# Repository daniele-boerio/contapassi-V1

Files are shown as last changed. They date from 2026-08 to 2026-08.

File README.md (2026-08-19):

# Setup Claude Code — contapassi

## Struttura del repo

```
contapassi/
├── .claude/
│   ├── CLAUDE.md                       ← contesto sempre caricato
│   └── skills/
│       ├── kicad-jlcpcb/SKILL.md
│       ├── nrf52840-firmware/SKILL.md
│       └── analisi-andatura/SKILL.md
├── .gitignore
├── README.md
│
├── docs/
│   ├── 01-design.md
│   ├── 02-bom-jlcpcb.md
│   ├── 03-firmware-taratura.md
│   └── datasheet/              ← E73, LSM6DSV16X, MCP73831, cella
│
├── hardware/
│   ├── contapassi.kicad_pro
│   ├── contapassi.kicad_sch
│   ├── contapassi.kicad_pcb
│   ├── lib/
│   │   ├── contapassi.kicad_sym
│   │   ├── contapassi.pretty/  ← footprint
│   │   └── 3dmodels/
│   └── production/
│       └── 2026-XX-XX-v1/      ← gerber + BOM + CPL di ogni ordine
│
├── firmware/
│   ├── CMakeLists.txt
│   ├── prj.conf
│   ├── boards/                 ← definizione board custom
│   └── src/
│
├── analysis/
│   ├── notebooks/
│   ├── src/                    ← parser, ZUPT, metriche
│   └── data/
│       ├── raw/                ← dump binari (NON versionati)
│       └── ground-truth.csv    ← versionato, è prezioso
│
└── ios/
```

### Le scelte che contano

**`lib/` va dentro `hardware/`.** KiCad risolve le librerie di progetto con
`${KIPRJMOD}`, che punta alla cartella del `.kicad_pro`. Fuori da lì i percorsi
si rompono appena sposti il progetto.

**Un solo repo, non tre.** Hardware, firmware e analisi cambiano insieme: se
sposti un pin nello schematico devi toccare anche il firmware. Con repo separati
quella correlazione si perde, e il CLAUDE.md andrebbe duplicato.

**`hardware/production/` con una cartella datata per ordine.** I file di
produzione sono generati, ma sono l'unica traccia di _cosa hai effettivamente
ordinato_. Quando la scheda arriva e qualcosa non torna, vuoi guardare i file
spediti — non rigenerarli da un progetto nel frattempo modificato.

**`firmware/boards/` non è opzionale.** L'nRF Connect SDK ha bisogno di una
definizione di board per il PCB custom: è lì che si dichiara quali pin sono SPI,
dove stanno gli interrupt e la configurazione del quarzo. È la traduzione in
codice della mappatura pin del doc 01.

**`analysis/data/raw/` fuori da git** — sono ~27 MB al giorno di dump, il repo
diventerebbe ingestibile in una settimana. Tienili in una cartella sincronizzata
o su un disco esterno.

**`ground-truth.csv` invece va versionato.** È piccolo e irripetibile: sono le
camminate fatte contando i passi a mano. Se lo perdi, rifai tutta la raccolta.

### .gitignore minimo

```gitignore
# KiCad
*-backups/
*.kicad_prl
*.bak
fp-info-cache
~*.*

# Firmware
build/

# Analisi
analysis/data/raw/
__pycache__/
.ipynb_checkpoints/
```

`.kicad_prl` è escluso ma `.kicad_pro` no: il primo contiene preferenze locali di
visualizzazione, il secondo le impostazioni di progetto da condividere.

## CLAUDE.md vs skill — la differenza

**CLAUDE.md** viene caricato in ogni conversazione. Contiene solo ciò che serve
sempre: cos'è il progetto, le decisioni congelate, i vincoli non negoziabili.
Tenerlo corto è importante — occupa contesto a ogni messaggio.

**Le skill** si caricano solo quando servono, in base alla loro `description`.
Contengono il dettaglio operativo di un dominio specifico. Le tre qui sono
disgiunte: hardware/produzione, firmware, analisi dati.

## Le tre skill

| Skill | Si attiva su |
| --- | --- |
| `kicad-jlcpcb` | KiCad, schematico, PCB, footprint, BOM, CPL, componenti, ordini |
| `nrf52840-firmware` | Codice firmware, driver, BLE, interrupt, consumo, bring-up |
| `analisi-andatura`  | Python, notebook, ZUPT, stance detection, taratura, validazione |

## Verifica che funzionino

In Claude Code, `/skills` elenca le skill disponibili. Se una non compare,
controlla che il frontmatter YAML sia valido e che `name` coincida con il nome
della cartella.

Per testare il triggering, prova richieste generiche e osserva se la skill si
attiva:

- "aggiungi un condensatore di bypass all'IMU" → `kicad-jlcpcb`
- "perché il consumo in idle è più alto del previsto?" → `nrf52840-firmware`
- "il conteggio passi sbaglia sulle camminate lente" → `analisi-andatura`

Se una skill non si attiva quando dovrebbe, il problema è quasi sempre nella
`description`: aggiungi i termini che l'utente userebbe realmente. Le descrizioni
sono volutamente "spinte" (elencano molti sinonimi e casi generici) proprio
perché la tendenza tipica è di non attivarle abbastanza.

## Manutenzione

Le skill contengono numeri che possono cambiare — budget energetico, quote,
codici LCSC. Quando un documento in `docs/` cambia, **controlla se la skill
corrispondente ripete quel numero**. Meglio ancora: dove possibile la skill
rimanda al documento invece di duplicare il valore.

I punti attualmente duplicati e da tenere allineati:

- budget ~161 µA e autonomia ~10 giorni (CLAUDE.md, firmware)
- quote PCB 24 × 41 mm (kicad-jlcpcb)
- codice LCSC del modulo `C356849` (CLAUDE.md, kicad-jlcpcb)
- configurazione IMU ±16 g / 416 Hz (firmware, analisi)

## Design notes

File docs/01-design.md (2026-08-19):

# Contapassi ad alta precisione — Documento di design

**Versione doc:** 1.1
**Stato:** requisiti congelati, **mappatura pin verificata (§5)**, schematico da disegnare
**Target produzione:** KiCad 9.0 → JLCPCB (PCB + PCBA)

---

## 1. Obiettivo

Dispositivo indossabile da caviglia per misurare con precisione:

- **conteggio passi** (24/7)
- **distanza percorsa** (errore target < 1%)
- **parametri di andatura**: cadenza, tempo di appoggio/volo, variabilità del passo

Sincronizzazione con iPhone via BLE, scrittura su HealthKit.
Autonomia target: **1 settimana** (progettato per ~10 giorni reali).
**Indossabile in continuo**, doccia e piscina incluse — mai da togliere.

### Non obiettivi (esplicitamente esclusi)

- Asimmetria destra/sinistra → richiede due unità sincronizzate
- Cinematica del tronco (tilt/obliquità/rotazione pelvica) → richiede posizione lombare
- Classificazione posturale (seduto/in piedi/sdraiato) → impossibile da caviglia
- Display, GPS, cardiofrequenzimetro

---

## 2. Decisione di posizionamento

**Scelta: caviglia**, sopra il malleolo.

| Criterio | Caviglia | Lombare (L3-L5) |
|---|---|---|
| Conteggio passi | ✅ superiore (cammino lento/strascicato) | buono |
| Distanza | ✅ **< 1% via ZUPT**, senza calibrazione | 2-4% via modello, calibrazione personale |
| Eventi temporali (heel strike, toe off) | ✅ precisi al ms | indiretti |
| Cinematica tronco | ❌ | ✅ |
| Asimmetria dx/sx con 1 device | ❌ | ✅ |
| Postura | ❌ | ✅ |
| Qualità RF | ❌ 10 cm da terra, peggiore | ✅ |
| Vincolo ingombro | ✅ permissivo | 4-5 mm max (schienale sedia) |

**Motivazione:** priorità dichiarata = passi + distanza. Lo ZUPT è possibile solo
dove il segmento corporeo si ferma completamente a ogni passo, cioè al piede/caviglia.

---

## 3. Principio ZUPT (Zero Velocity Update)

L'integrazione dell'accelerazione per ottenere posizione accumula errore
quadraticamente: in ~10 s la stima è inutilizzabile.

A ogni passo però il piede resta **fermo a terra per ~0,3-0,5 s**. In quella
finestra la velocità reale è nota e vale zero. Quindi:

1. Rileva la fase di appoggio (stance detection)
2. Azzera velocità e correggi la deriva del giroscopio
3. Integra solo la fase di volo successiva
4. Ripeti

L'errore non si accumula mai oltre una singola falcata.
Analogia: NTP che risincronizza un clock che deriva.

**Conseguenza architetturale:** il giroscopio deve essere attivo durante *tutto*
il cammino, non a campione. Non è duty-ciclabile.

---

## 4. Architettura hardware

```
  pogo (+) ──▶ TVS + prot. inversione ──▶ MCP73831 ──▶ LiPo 301220 (80 mAh, con PCM)
                                              │              │
                                            /STAT            │
                                              │              ▼
                                         ┌────┴───────────  VDH  (VDDH)
                                         │  E73-2G4M08S1C
                                L1 ──── DCH   (nRF52840)
                             (~10 µH)     │                   │
                                  SWD ────┤              2.4 GHz ~~~
                                         │
                          Y1 ─── XL1/XL2 ─┤
                     (32,768 kHz + 2C)    │
                                         │
                        ┌─── SPI condiviso ───┐
                        │                     │
                 LSM6DSV16XTR            W25Q256JVEIQ
               (CS1 + INT1/INT2)           (CS2)
                                        [SOLO v1]
```

Dominio di tensione: **3,0 V** (REGOUT0 configurato via UICR — vedi doc 02 §3).

Topologia di alimentazione verificata sulla *circuit configuration no. 4* del
datasheet Nordic (VDDH + EXTSUPPLY + DCDCEN0 + DCDCEN1):

- LiPo → `VDH` (VDDH)
- **L1 = 10 µH** tra `DCH` (DCCH) e `VDD`: l'induttore sta sull'uscita di REG0,
  non sull'ingresso. Nordic specifica IDC ≥ 80 mA, ±10%, 0603
- `VDD` (pad 19) è **l'uscita di REG0 a 3,0 V** e alimenta IMU e flash.
  Richiede `EXTSUPPLY` abilitato nell'UICR (vedi doc 02 §3)

> ⚠️ **VEXDIF = 0,3 V.** REG0 non può regolare più vicino di 0,3 V al VDDH.
> Con REGOUT0 = 3,0 V il rail è garantito solo finché la cella sta **sopra
> 3,3 V**; sotto, VDD scende seguendo VDDH − 0,3 V. Vedi doc 02 §3.

### 4.1 Decisioni chiave e motivazioni

| # | Decisione | Motivo |
|---|---|---|
| 1 | **Pedometro in hardware nel sensore + FIFO** | MCU sveglio < 1% del tempo. È ciò che rende possibile una cella da poche decine di mAh. Event-driven, mai polling |
| 2 | **Modulo radio certificato, non chip nudo** | Antenna 2.4 GHz già progettata, adattata e certificata. Elimina una classe di problemi non diagnosticabili senza strumenti RF |
| 3 | **Batteria diretta su VDDH** | L'nRF52840 ha regolatore interno, accetta fino a 5,5 V. Elimina l'LDO esterno |
| 4 | **SPI condiviso, non QSPI dedicato** | Il collo di bottiglia del dump è il BLE (~150 kB/s), non la flash. Libera 4 pin, semplifica il layout, e la flash si rimuove pulitamente in v2 |
| 5 | **ZUPT sull'MCU, non su MLC del sensore** | Con budget da 1 settimana l'ottimizzazione non serve più. In C sull'MCU si debugga con un breakpoint, nella FSM del sensore no |
| 6 | **Niente fuel gauge dedicato** | ADC interno + partitore VDDHDIV5 già integrato. Sufficiente su 1 settimana |
| 7 | **v1 logger, v2 prodotto** | Algoritmo tarato sui propri dati, sviluppato offline in Python. Ciclo di iterazione in secondi anziché ore |
| 8 | **DFU over BLE dal giorno 1** | La capsula è annegata in resina: dopo il potting non esiste accesso via cavo |
| 9 | **Doppio tap come unico "pulsante"** | Rilevamento in hardware nell'IMU. Zero componenti, zero aperture, funziona attraverso la resina |
| 10 | **Capsula separata dal cinturino** | Il cinturino è la parte che si consuma e va iterata più volte. Non deve portarsi via l'elettronica |
| 11 | **Dominio a 3,0 V** (REGOUT0 via UICR) | Il default sarebbe 1,8 V. A 3,0 V restano compatibili flash standard, LED di qualsiasi colore e debugger a 3,3 V fissi. Il guadagno energetico a 1,8 V è marginale |
| 12 | **Induttore REG0 esterno (L1)** | Il modulo E73 espone `DCH` → non è integrato. Senza, REG0 resta in LDO e dissipa il 25% su tutto il consumo della scheda |
| 13 | **Quarzo 32,768 kHz esterno (Y1)** | Il modulo espone `XL1`/`XL2` → non è integrato. Senza, l'RC interno allarga le finestre RX BLE e consuma di più proprio dove ottimizziamo |

---

## 5. Mappatura pin — ricostruita sul pinout Ebyte

**Stato:** ✅ **verificata il 2026-08-19.** Fonti:

- *E73-2G4M08S1C User Manual* v1.9 (Ebyte, 2020-03-30), §3 "Size and pin definition"
  → copia locale in `docs/datasheet/`
- *nRF52840 Product Specification*, tabella pin aQFN73 e §56.4 "Circuit
  configuration no. 4" (VDDH + EXTSUPPLY + DCDCEN0 + DCDCEN1 — la nostra topologia)
- footprint generato con `easyeda2kicad --full --lcsc_id=C356849` (geometria dei pad)

### 5.1 Vincolo scoperto: pin "low frequency I/O only"

Nordic marca una parte dei GPIO come **"Standard drive, low frequency I/O only"**,
dove *low frequency* è definita come **segnale fino a 10 kHz**. Su questi pin non
si può appoggiare un bus SPI.

Tra i pad esposti dall'E73 appartengono a questa classe:

`P0.02` `P0.03` `P0.28` `P0.29` `P0.30` `P0.31` (AIN0-1 e AIN4-7),
`P0.09` `P0.10` (NFC), `P1.02` `P1.04` `P1.06` `P1.10` `P1.11` `P1.13`.

**Non** ne fanno parte `P0.04`/`AIN2` e `P0.05`/`AIN3`: hanno funzione analogica
ma nessuna restrizione in frequenza. `P1.00`, `P1.09` e tutta la fascia
`P0.06`-`P0.08`, `P0.12`-`P0.17`, `P0.20`-`P0.26` sono a piena velocità.

> Su 43 pad, i GPIO davvero utilizzabili per SPI ad alta frequenza sono 13.
> È il vincolo che ha determinato l'assegnazione qui sotto.

### 5.2 Pad del modulo

Fila **E** = fila esterna (pad dispari sul lato corto), **I** = fila interna
(pad pari, sotto il corpo del modulo → escape obbligatoriamente su strato interno).

| Pad | Serigrafia | nRF52840 | Classe | Uso nel progetto |
|---|---|---|---|---|
| 1 | `P1.11` | P1.11 | LF | libero |
| 2 | `P1.10` | P1.10 | LF | libero |
| 3 | `P0.03` | P0.03/AIN1 | LF | libero |
| 4 | `AI4` | P0.28/AIN4 | LF | libero |
| 5 | `GND` | — | power | GND |
| 6 | `P1.13` | P1.13 | LF | libero |
| 7 | `AI0` | P0.02/AIN0 | LF | libero |
| 8 | `AI5` | P0.29/AIN5 | LF | libero |
| 9 | `AI7` | P0.31/AIN7 | LF | ✅ **LED** |
| 10 | `AI6` | P0.30/AIN6 | LF | ✅ **CHG_STAT** |
| 11 | `XL1` | P0.00/XL1 | — | ✅ **Y1** |
| 12 | `P0.26` | P0.26 | full, I | ✅ **SPI MISO** |
| 13 | `XL2` | P0.01/XL2 | — | ✅ **Y1** |
| 14 | `P0.06` | P0.06 | full, I | ✅ **SPI MOSI** |
| 15 | `AI3` | P0.05/AIN3 | full, E | ✅ **IMU_INT1** |
| 16 | `P0.08` | P0.08 | full, I | ✅ **SPI SCK** |
| 17 | `P1.09` | P1.09 | full, E | ✅ **IMU_INT2** |
| 18 | `AI2` | P0.04/AIN2 | full, I | riserva (portare a test pad) |
| 19 | `VDD` * | VDD | power | ✅ **rail 3,0 V** (uscita REG0) |
| 20 | `P12` | P0.12 | full, I | ✅ **CS_FLASH** |
| 21 | `GND` | — | power | GND |
| 22 | `P0.07` | P0.07 | full, I | ✅ **CS_IMU** |
| 23 | `VDH` | VDDH | power | ✅ **LiPo diretta** |
| 24 | `GND` | — | power | GND |
| 25 | `DCH` | DCCH | power | ✅ **L1 10 µH → VDD** |
| 26 | `RST` | P0.18/RESET | reset | test pad |
| 27 | `VBS` | VBUS | power | non collegato |
| 28 | `P15` | P0.15 | full | libero |
| 29 | `D-` | USB D- | — | non collegato |
| 30 | `P17` | P0.17 | full | libero |
| 31 | `D+` | USB D+ | — | non collegato |
| 32 | `P0.20` | P0.20 | full | libero |
| 33 | `P0.13` | P0.13 | full | libero |
| 34 | `P0.22` | P0.22 | full | libero |
| 35 | `P0.24` | P0.24 | full | libero |
| 36 | `P1.00` | P1.00 | full | libero |
| 37 | `SWD` | SWDIO | debug | ✅ **pad SWD** |
| 38 | `P1.02` | P1.02 | LF | libero |
| 39 | `SWC` | SWDCLK | debug | ✅ **pad SWD** |
| 40 | `P1.04` | P1.04 | LF | libero |
| 41 | `NF1` | P0.09/NFC1 | LF + NFC | ❌ non usare |
| 42 | `P1.06` | P1.06 | LF | libero |
| 43 | `NF2` | P0.10/NFC2 | LF + NFC | ❌ non usare |

\* Il simbolo EasyEDA chiama questo pad `VCC`; il manuale Ebyte lo chiama `VDD`.
È lo stesso pad 19.

### 5.3 Geometria dei pad

Dal footprint generato (origine al centro del modulo, 13 × 18 mm):

- **Lato corto "freddo"** (pad 11-25), opposto all'antenna: due file sfalsate,
  dispari sulla fila esterna, pari sulla fila interna (sotto il corpo)
- **Lati lunghi**: pad 1-10 su un lato, pad 26-43 sull'altro, anch'essi sfalsati
- **Antenna**: striscia di ~2,2 mm sul lato corto opposto ai pad 11-25 → è lì
  che va il keepout

### 5.4 Assegnazione funzionale — congelata

| Segnale | nRF52840 | Pad | Note |
|---|---|---|---|
| SPI SCK | `P0.08` | 16 | piena velocità |
| SPI MOSI | `P0.06` | 14 | piena velocità |
| SPI MISO | `P0.26` | 12 | piena velocità |
| CS_IMU | `P0.07` | 22 | pull-up 10k |
| CS_FLASH | `P0.12` | 20 | pull-up 10k — **non montato in v2** |
| IMU_INT1 | `P0.05` | 15 | watermark FIFO |
| IMU_INT2 | `P1.09` | 17 | wake / doppio tap |
| CHG_STAT | `P0.30` | 10 | open-drain, pull-up 100k |
| LED | `P0.31` | 9 | resistore in serie |
| riserva | `P0.04` | 18 | unico pin veloce ancora libero sul lato freddo |

### 5.5 Perché questa assegnazione

1. **Tutto il traffico veloce sul lato corto opposto all'antenna.** SPI, interrupt
   e alimentazione escono dallo stesso lato: le tracce commutanti non passano mai
   vicino all'antenna, e IMU e flash si piazzano tutti in quella zona.
2. **Interrupt sulla fila esterna** (pad 15 e 17): sono gli unici due pin veloci
   della fila esterna del lato freddo, e non richiedono escape sotto il modulo.
3. **CHG_STAT e LED sui pin LF** del lato lungo, quelli più vicini al lato freddo:
   sono segnali lenti, sprecare pin veloci su di loro sarebbe stato un errore.
4. **`P0.04` tenuto libero**: è l'ultima risorsa veloce. Portarlo a un test pad
   costa nulla ora e vale molto se in bring-up serve una linea in più.

### 5.6 Pin vietati

| Pin | Motivo |
|---|---|
| `P0.00` / `P0.01` (pad 11/13) | quarzo 32,768 kHz (Y1) |
| `P0.09` / `P0.10` (pad 41/43) | NFC di default; usabili come GPIO solo via UICR `NFCPINS`, e sono comunque LF |
| `P0.18` (pad 26) | reset |
| tutti i pin **LF** | mai per SCK/MOSI/MISO — vedi §5.1 |

### 5.7 Conseguenze sul layout

- I cinque segnali SPI escono da pad della **fila interna**, sotto il corpo del
  modulo: l'escape va fatto con via verso uno strato interno. Ebyte raccomanda
  esplicitamente di **non** far passare routing digitale veloce sullo strato
  opposto sotto il modulo e di mettere rame ben collegato a massa sotto l'area di
  contatto → **L2 piano di massa continuo sotto il modulo**, segnali su L3.
- I pad `SWD`/`SWC` (37/39) stanno sul lato lungo, dalla parte dell'antenna: le
  tracce verso i test pad vanno portate sul lato freddo restando fuori dalla zona
  di keepout.
- `DCH` (25) è il nodo di commutazione di REG0: L1 va tenuto corto e il loop
  `VDH` → L1 → `VDD` compatto, lontano da `XL1`/`XL2` (pad 11/13).

---

## 6. Budget energetico

Assunzioni: cella **301220** (80 mAh dichiarati, 60 prudenti), derating 85%,
DC/DC attivo, sync oraria, advertising 2 s. L'autonomia scala linearmente con la capacità reale:
0,161 mA × 24 h = **3,9 mAh al giorno**.

| Voce | Corrente |
|---|---|
| Idle (accel LP + pedometro, MCU sleep, flash DPD, leakage) | 26 µA |
| Sessioni giroscopio (ZUPT, ~90 min/giorno) | 123 µA |
| Radio (advertising + connessioni) | 10 µA |
| Varie | 2 µA |
| **Totale** | **~161 µA** |
| **Autonomia** | **~18 giorni** sugli 80 mAh dichiarati, **~13 giorni** sui 60 mAh prudenti |

> ⚠️ Valori tipici da datasheet a 25 °C / 3,0 V. **Da verificare sul silicio
> reale** appena la board è funzionante.

**Fase di taratura (v1):** la flash assorbe ~20 mA in scrittura → circa +200 µA
medi durante il logging, cioè ~361 µA totali. Autonomia in logging **~6-8
giorni**: una settimana di camminate si registra senza toccare il caricabatterie.

---

## 7. Meccanica

| Parametro | Valore |
|---|---|
| PCB | **24 × 41 mm**, 4 strati, spessore 0,8 mm |
| Capsula | **~28 × 45 × 5,1 mm** |
| Cella | LiPo **301220** (3,0 × 12 × 20 mm), **80 mAh dichiarati**, PCM integrato |
| Costruzione | Capsula rigida in resina (potting) + guaina silicone platinico separata |

> ⚠️ **Quote cresciute** rispetto al piano iniziale (26 × 14 mm / 30 × 16 × 5 mm):
> il modulo E73 è 18 × 13 mm, contro i 15,5 × 10,5 mm dell'MDBT50Q previsto.
> Alla caviglia, sotto i pantaloni, resta comodo — ma l'outline va fissato ora.

### Disposizione "corta e larga" — decisa il 2026-08-20

Il vincolo dichiarato è: **capsula bassa, ma non lunga**. 61 mm non sono
indossabili, e il modulo da solo ne occupa 18.

Niente si sovrappone in verticale, ma invece di mettere tutto in fila si sfrutta
la **larghezza**: la cella occupa mezza scheda in larghezza, e nell'altra metà
ci stanno carica e alimentazione.

| Zona | Y | Faccia superiore | Faccia inferiore |
|---|---|---|---|
| **cella** | 0-21 mm | a destra solo rame (pogo, pad di test), a sinistra carica e alimentazione | **cella** 12 × 20, a destra |
| **modulo** | 22-41 mm | modulo a sinistra, striscia componenti a destra (IMU, flash, quarzo) | libera |
| **antenna** | 37,4-41 mm | keepout su tutti e 4 gli strati | keepout |

**Spessore: 0,8 (PCB) + 3,3 (cella con tolleranza) + 2 × 0,5 (resina) = 5,1 mm.**
Scheda 24 × 41 mm, capsula ~28 × 45 × 5,1 mm.

Assemblaggio **su una faccia sola**: sul retro c'è solo la cella, incollata. I due
fili passano in fori passanti e si saldano davanti.

### Il modulo è il pavimento: 3,0 mm

Sotto i 4,8 mm non si scende senza cambiare modulo. Le tre voci:

- **modulo E73: 3,00 ± 0,1 mm** — ✅ confermato sul **disegno meccanico** del
  manuale Ebyte (pag. 6), non solo sul modello 3D. Modulo completo:
  18,0 ± 0,1 × 13,0 ± 0,1 × 3,00 ± 0,1 mm, 43 pad
- PCB 0,8 mm — già il minimo sensato a 4 strati
- pareti di resina 0,5 mm per lato

Tutto il resto (IMU 0,83, flash 0,8, carica ~1,1, bulk 1206 ~1,6) sta comodamente
sotto i 3,0 mm e non tocca il totale, perché vive nella zona B dove la faccia
opposta è vuota.

### Cella: 301220, e perché non una più grande

La 401220 del piano iniziale era spessa 4,0 mm e da sola avrebbe portato la
capsula a 5,8 mm. La 301220 è la stessa pianta, 1 mm più sottile.

**La larghezza della cella è vincolata, non libera.** La cella occupa metà della
larghezza della scheda; l'altra metà serve per carica e alimentazione, che
devono stare vicino ai pad del modulo. Una cella da 20 mm di larghezza (es. la
302025 da 140 mAh) lascerebbe 3 mm: non ci sta niente, e L1 finirebbe a 10 mm
dal pad `DCH` invece che a 4.

| | Capacità | Larghezza | Effetto |
|---|---|---|---|
| **301220** ✅ | 80 mAh dichiarati | 12 mm | resta spazio per l'alimentazione |
| 302025 | ~140 mAh dichiarati | 20 mm | scheda +14 mm oppure alimentazione lontana dal modulo |

80 mAh × 0,85 ÷ 0,161 mA = **~18 giorni**, ben oltre il requisito di §1. La
capacità in più della 302025 non serviva e costava lunghezza.

### Dati della cella acquistata

Fonte: pagina del venditore (AliExpress, modello 301220, ~4,7 €/pz in confezione
da 3). Non è un datasheet, ma dichiara i parametri che servono.

| Parametro | Valore | Conseguenza |
|---|---|---|
| Dimensioni | 3 × 12 × 20 mm | ✅ combacia con la zona cella del layout |
| Capacità | 80 mAh dichiarati | autonomia ~18 giorni |
| **PCM** | **integrato** ✅ | requisito soddisfatto |
| Corrente di carica max | **1C** = 80 mA | i nostri 50 mA sono 0,63C ✅ |
| Carica standard | 0,5C CC fino a 4,25 V, poi CV | il MCP73831 fa esattamente questo |
| Scarica max | 1C | irrilevante: noi tiriamo 0,16 mA |
| Fine scarica | **2,75 V** | ⚠️ vedi sotto |
| Fili | liberi, rosso/nero | ✅ vanno diretti nei due fori di J2 |

> ⚠️ **I 80 mAh sono ottimistici.** 3 × 12 × 20 mm fanno 0,72 cm³, cioè
> 411 Wh/l: sopra quello che ci si aspetta da una cella piccola con PCM
> (250-350). **Contare su 55-70 mAh reali** → 12-15 giorni. Misurare la capacità
> vera alla prima carica completa.

> 🔴 **Il PCM stacca a 2,75 V, ma la flash muore prima.** Con VEXDIF = 0,3 V
> (doc 02 §3.2), a cella 2,75 V il rail vale ~2,45 V, sotto il minimo della
> W25Q256JV (2,7 V). La protezione della cella **non** protegge i dati: il
> firmware deve smettere di scrivere in flash sotto i ~3,2 V di cella, molto
> prima che intervenga il PCM.

> **Perché allungare non dà fastidio.** L'asse lungo della capsula corre **lungo
> la gamba**, dove il profilo è quasi rettilineo: 52 mm sopra il malleolo ci
> stanno. È la *larghezza* che deve avvolgere la circonferenza, e resta a 21 mm.

### Vincoli non negoziabili

1. **Antirotazione.** Il sensore misura su tre assi fissi: hanno significato solo
   se l'orientamento rispetto alla gamba è ripetibile. Serve **incastro con
   chiavetta meccanica**, non attrito.
2. **Keepout antenna.** Sotto l'antenna del modulo: nessun rame su nessuno strato,
   nessuna vite, **e mai la sacca LiPo** (è alluminio, spegne l'antenna).
   Il modulo va a un'estremità, con il lato antenna che sporge oltre il bordo
   della cella. Quell'estremità orientata **verso l'alto** sulla gamba.
3. **Vincolo agli urti.** 10-16 g a ogni tallonata. La cella va bloccata con
   schiuma precompressa prima del potting: nessuna massa libera, nessun
   componente alto.
4. **Cinturino sopra il malleolo**, dove la gamba si allarga: il conico impedisce
   lo scivolamento verso il basso.
5. **Pogo pin sulla faccia esterna**, non contro la pelle (sudore + contatti =
   accoppiamento pessimo). Recessati in una scanalatura per non strisciarli
   sui pantaloni.

### Tenuta stagna

Requisito: **doccia e piscina senza toglierlo**. Il potting previsto per gli urti
risolve anche l'acqua — stessa scelta, doppio beneficio. La pressione non è il
vincolo (una piscina è ~0,2 bar): il vincolo è la **tenuta nel tempo**.

| Punto | Requisito |
|---|---|
| Pogo pin | Unico foro nella capsula. Già sulla faccia esterna |
| Cella LiPo | **Sigillata completamente**, non solo protetta. È il componente che soffre di più l'umidità nel lungo periodo |
| Guaina | Silicone platinico: regge cloro e acqua salata |

**🔴 Regola d'uso da mettere nell'app:** mai in carica se bagnato.
Contatti umidi + corrente = corrosione garantita. In acqua senza tensione
applicata non succede nulla; il danno avviene al momento della ricarica.
Sciacquare con acqua dolce dopo il mare.

> **Perché non si toglie:** rimetterlo con un orientamento diverso rompe la
> ripetibilità dei dati — lo stesso motivo per cui esiste la chiavetta
> antirotazione. Meglio un dispositivo che riconosce il nuoto (doc 03 §5)
> che uno da togliere e rimettere.

### Scartato

**Batteria distribuita nel cinturino** per assottigliare la capsula: richiede un
flex che si flette a ogni passo per mesi. Modo affidabile di introdurre un guasto
intermittente impossibile da diagnosticare.

---

## 8. Comunicazione iPhone

Nessun MFi richiesto: BLE con GATT custom + app propria.

### Due canali separati

| | Sync sommario | Dump grezzo |
|---|---|---|
| Contenuto | Passi/ora, distanza, batteria | Log completo a 416 Hz |
| Frequenza | Ogni ora, pochi secondi | Solo sotto carica, solo v1 |
| Volume | Centinaia di byte | Decine di MB |

Con **2M PHY + Data Length Extension** su iPhone: ~120-170 kB/s reali.

### Vincoli iOS da rispettare in fase di progetto

1. **MTU:** iOS accetta fino a 185 byte di payload nelle notifiche. Usa
   **notifiche, non indicazioni** (le indicazioni aspettano l'ack → throughput
   dimezzato).
2. **Connection interval:** Apple impone minimo 15 ms e multiplo di 15. Parametri
   non conformi vengono rifiutati e resti sui default.
   Sync sommario → intervallo lungo + slave latency alta. Dump → intervallo minimo.
3. **Background:** serve il background mode `bluetooth-central` con **State
   Preservation and Restoration**. In background iOS scansiona **solo per UUID di
   servizio espliciti**, mai wildcard → l'UUID custom va cablato nell'app.
4. **Advertising:** 2 s di default (pochi µA). Finestra veloce solo su evento
   (movimento rilevato, dispositivo sul caricatore).

### HealthKit

Scrittura come `HKQuantityTypeIdentifier.stepCount`.

> ⚠️ Anche l'iPhone scrive i propri passi. Salute **non somma** le sorgenti
> sovrapposte: sceglie in base alla priorità delle sorgenti impostata dall'utente.
> Va gestito: o si accetta la priorità utente, o si tengono i propri dati in un
> contenitore separato usando HealthKit solo per un totale consolidato.

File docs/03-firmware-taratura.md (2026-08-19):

# Firmware e protocollo di taratura

**Principio guida:** prima si esplorano i dati in un notebook, poi si porta in
produzione. Scrivere l'algoritmo prima di avere i propri dati significa tararlo
sull'andatura di qualcun altro.

---

## 1. Le due versioni

| | **v1 — Logger** | **v2 — Prodotto** |
|---|---|---|
| Hardware | Con flash W25Q256JVEIQ | Flash non montata (DNP) |
| Firmware | Solo acquisizione e scrittura | Algoritmo in C a bordo |
| Algoritmi | Nessuno | ZUPT, pedometro, metriche |
| Elaborazione | Offline in Python sul PC | Real-time sul dispositivo |
| Autonomia | 2-4 giorni | ~10 giorni |
| Scopo | Raccogliere dataset personale | Uso quotidiano |

**Vantaggio del logger:** ciclo di iterazione in secondi anziché ore, con grafici.
Sul firmware ogni prova richiede compilazione, flash, camminata, scarico.

---

## 2. Firmware v1 (logger)

### Pin (dal doc 01 §5.4 — unica fonte, non riscriverli a mano)

| Segnale | nRF52840 |
|---|---|
| SPI SCK / MOSI / MISO | `P0.08` / `P0.06` / `P0.26` |
| CS_IMU / CS_FLASH | `P0.07` / `P0.12` |
| IMU_INT1 / IMU_INT2 | `P0.05` / `P1.09` |
| CHG_STAT / LED | `P0.30` / `P0.31` |
| riserva | `P0.04` |

> `P0.30` e `P0.31` sono pin **"low frequency I/O only"** (≤ 10 kHz): vanno bene
> per un LED e per uno stato di carica, mai per un bus.

### Vincoli che arrivano dallo schematico

- **LED in erogazione, non in assorbimento.** `P0.31` → 1 kΩ → LED → GND: a
  3,0 V con un LED rosso scorre ~1 mA, sopra i 0,5 mA garantiti dal drive
  standard. Configurare il pin in **HIGH drive** (`H0H1`), altrimenti il LED
  resta smorto e la tensione di uscita non è quella attesa
- **Tensione di batteria: nessun partitore.** Si legge con il SAADC sull'ingresso
  interno **VDDHDIV5** (VDDH diviso 5). Non c'è hardware da pilotare, ma il
  fattore 5 va rimesso nel conto
- **`CHG_STAT` è open-drain** con pull-up da 100 kΩ: basso = in carica, alto =
  carica finita **oppure caricatore assente**. I due casi si distinguono solo
  incrociando con la tensione di VDDH
- **Flash: `WP#` e `HOLD#` sono tirati alti con 10 kΩ**, non collegati fissi a
  VDD. In v1 vanno lasciati in pace; servono se un giorno si volesse il quad SPI
- **`P0.04` è portato a un pad di test** ed è l'unico GPIO veloce ancora libero

### Funzioni minime

- Configurazione IMU: **±16 g, 416 Hz, 6 assi**
  *(gli impatti tibiali in corsa superano i 16 g; 416 Hz serve per timbrare bene
  heel strike e toe off)*
- FIFO del sensore + interrupt watermark su INT1
- Buffer in RAM, **scrittura su flash a blocchi grossi**
- Pedometro hardware attivo in parallelo (per il gating)
- DFU over BLE
- Dump della flash via BLE quando sul caricatore

### ⚠️ Regola non negoziabile: scrittura a blocchi

La W25Q assorbe ~20 mA in scrittura. Chiamarla a ogni campione distrugge il budget
energetico. L'nRF52840 ha 256 kB di RAM: accumulare lì e svuotare a blocchi.

### ⚠️ Il logging deve essere gattato

Data rate: 6 assi × 16 bit × 416 Hz ≈ **5,0 kB/s → 18 MB/h**.

Su 32 MB → solo ~1,8 h di registrazione continua.

**Soluzione:** attivare il logging solo sui bout di cammino rilevati dal pedometro
hardware. Si scende a ~27 MB/giorno di dati effettivamente utili, e non si portano
a casa 15 ore di rumore da stare seduto.

### Formato dei dati

Includere sempre nel record:

- Timestamp (o contatore campioni + timestamp di blocco)
- 3 assi accelerometro
- 3 assi giroscopio
- Marker di inizio/fine sessione
- Temperatura (utile per valutare la deriva del giroscopio)

---

## 3. Protocollo di raccolta dati

### Sessione base — pista di atletica (400 m)

Registrare **5 andature**, ciascuna su distanza nota, contando i passi a mano:

| # | Andatura | Distanza | Note |
|---|---|---|---|
| 1 | Camminata molto lenta | 200 m | Il caso peggiore per i contapassi |
| 2 | Camminata normale | 400 m | — |
| 3 | Camminata veloce | 400 m | — |
| 4 | Corsa leggera | 400 m | — |
| 5 | Corsa sostenuta | 200 m | Verifica saturazione a ±16 g |

Per ognuna annotare: **distanza reale, passi contati a mano, tempo**.

### Sessione complementare — tapis roulant

Non sostituisce la pista, la integra. Il tapis dà **velocità impostabile,
ripetibile e controllata**; la pista dà la **verità assoluta sulla distanza**
(il display del tapis è calibrato sui giri del nastro, non è un riferimento
affidabile al livello di precisione cercato).

> **Perché i dati sono validi:** un nastro a velocità costante è un sistema di
> riferimento inerziale. Nel riferimento del nastro il piede è *davvero* fermo
> durante l'appoggio → **lo ZUPT resta valido** e le misure inerziali sono
> identiche a quelle di una camminata all'aperto alla stessa andatura.
> Nessuna gestione speciale nel firmware.

Sweep sistematico, 5 minuti per velocità:

| Velocità | Nota |
|---|---|
| 3 km/h | Camminata lenta |
| 4 km/h | Camminata normale |
| 5 km/h | Camminata veloce |
| 6 km/h | Transizione cammino/corsa |
| 8 km/h | Corsa leggera |
| 10 km/h | Corsa — verifica saturazione ±16 g |

Ripetere a pendenza 0% e 5% per valutare l'effetto sulla lunghezza di falcata.

**Limiti da tenere presenti:**

- **Transitori:** durante accelerazione/decelerazione del nastro il riferimento
  non è più inerziale → errore per qualche secondo. Scartare quelle finestre
- **Slittamento del nastro** sotto carico: piccolo errore, ma è del tapis
- **Pendenza:** misuri distanza percorsa, non dislivello (resti alla stessa quota).
  Corretto così — contare i piani richiederebbe il barometro, tolto passando
  alla caviglia

### Sessioni aggiuntive (casi difficili)

- Scale in salita e in discesa (conteggio gradini noto)
- Cammino in pendenza
- Cammino con carrello della spesa / passeggino
- Passi strascicati, cammino in casa a passi corti
- Alzarsi e fare 3-4 passi (i primi passi sono il caso peggiore)
- Falsi positivi: stare seduto muovendo la gamba, guidare, andare in bici
- Trasporto passivo: auto, treno, ascensore

### Regola di validazione

**Ogni registrazione deve avere una verità di riferimento annotata.** Un file senza
ground truth non serve a nulla e va scartato.

Tenere un log parallelo (foglio o note) con:
`data / ora inizio / tipo / distanza reale / passi contati / condizioni`

---

## 4. Sviluppo offline in Python

### Pipeline

1. **Parsing** del dump binario → DataFrame
2. **Verifica qualità**: campioni persi, saturazioni, gap temporali
3. **Stance detection** — rilevare le fasi di appoggio
4. **ZUPT** — azzeramento velocità + correzione deriva
5. **Integrazione** delle fasi di volo → lunghezza falcata
6. **Pedometro** — validare il conteggio contro i passi contati a mano
7. **Metriche di andatura** — cadenza, tempo appoggio/volo, variabilità

### Stance detection — approccio

Combinare più condizioni contemporaneamente su una finestra scorrevole:

- Modulo dell'accelerazione vicino a 1 g
- Varianza dell'accelerazione sotto soglia
- Modulo della velocità angolare sotto soglia

Nessuna delle tre da sola è affidabile. Le soglie vanno **tarate sui propri dati**,
ed è esattamente il motivo per cui esiste la fase v1.

### Metriche di andatura ottenibili

- **Cadenza** (passi/min)
- **Variabilità del tempo di passo** (CV) — la più interessante clinicamente
- **Tempo di appoggio / tempo di volo**
- **Durata del doppio supporto**
- **Regolarità** via autocorrelazione: primo picco = regolarità del passo,
  secondo picco = regolarità della falcata

> ❌ Non ottenibili da un solo dispositivo alla caviglia: asimmetria destra/sinistra,
> cinematica del tronco, postura.

### Criterio di uscita dalla fase v1

- [ ] Errore sul conteggio passi < 1% su tutte le andature testate
- [ ] Errore sulla distanza < 1% su percorsi noti
- [ ] Zero falsi positivi in auto/treno/seduto
- [ ] Algoritmo stabile su almeno 3 sessioni indipendenti senza ritaratura

---

## 5. Firmware v2 (prodotto)

### Struttura a eventi

```
MCU in sleep profondo
  │
  ├── INT1 (watermark FIFO) ──▶ svuota FIFO ──▶ elabora ──▶ sleep
  │
  ├── INT2 (movimento) ──────▶ attiva giroscopio, entra in modo cammino
  │
  ├── INT2 (doppio tap) ─────▶ azione utente (es. LED stato batteria)
  │
  ├── Timer 1 h ─────────────▶ advertising rapido, sync BLE, sleep
  │
  └── CHG_STAT ──────────────▶ modo carica: advertising rapido, dump disponibile
```

### Macchina a stati principale

| Stato | Accelerometro | Giroscopio | Consumo |
|---|---|---|---|
| **Idle** | LP + pedometro HW | spento | ~26 µA |
| **Cammino** | full rate | **attivo** (ZUPT) | ~alto |
| **Non deambulatoria** | LP | **spento** | basso |
| **Sync** | LP | spento | picchi TX |
| **Carica** | LP | spento | irrilevante |

Transizione Idle → Cammino: su rilevamento movimento sostenuto.
Transizione Cammino → Idle: dopo N secondi senza passi.
Transizione Cammino → Non deambulatoria: movimento presente ma **nessuna fase di
appoggio valida per N secondi consecutivi**.

**Il giroscopio è il costo dominante.** L'unica leva è entrare in stato Cammino
il più tardi possibile e uscirne il prima possibile — senza però perdere passi.

### 🔴 Stato "attività non deambulatoria"

**Il problema.** Lo ZUPT poggia su un'unica assunzione: che a ogni passo il piede
sia fermo. Nel nuoto, in bici e al remoergometro il piede **non si ferma mai**.
Con soglie permissive l'algoritmo integrerebbe accelerazioni senza mai correggere
la deriva → **distanze completamente inventate**. Non un errore piccolo: rumore.

Il conteggio passi invece è poco a rischio: il pedometro cerca l'impatto del
tallone, che in acqua non esiste.

**La firma inerziale del nuoto è ben distinguibile:**

| Grandezza | Cammino | Nuoto |
|---|---|---|
| Picchi di accelerazione | 10-16 g (tallonata) | 1-2 g |
| Fasi di quiete | Presenti a ogni passo | Assenti |
| Profilo | Impulsivo | Continuo, sinusoidale |
| Orientamento gravità | Stabile | Capovolto nel dorso |

**Comportamento in questo stato:**

- ZUPT sospeso
- Conteggio passi sospeso
- Giroscopio spento → **consumi meno che in stato Cammino**
- Periodo marcato nei dati come "attività non deambulatoria"

Costo implementativo: un ramo in più nella logica di transizione. Protegge anche
da bici e remoergometro, che hanno lo stesso identico problema.

> **Da aggiungere alle sessioni di raccolta (§3):** nuoto, bici, remoergometro.
> Servono per tarare le soglie di questa transizione.

### Dati mantenuti a bordo

- Passi per ora (buffer circolare, almeno 7 giorni)
- Distanza per ora
- Metriche di andatura aggregate per sessione
- Tensione batteria

Il buffer da 7 giorni serve a non perdere dati se l'iPhone non si connette.

### Servizio BLE

GATT custom. Caratteristiche minime:

| Caratteristica | Tipo | Contenuto |
|---|---|---|
| Sommario corrente | read/notify | Passi oggi, distanza, batteria |
| Storico | notify | Buffer orario, trasferito a blocchi |
| Stato dispositivo | read | Firmware, uptime, stato carica |
| Controllo | write | Reset contatori, sincronizza orologio |
| Dump grezzo | notify | Solo v1, solo sotto carica |

> ⚠️ **Sincronizzazione orologio a ogni connessione.** Se il modulo non ha il
> quarzo a 32,768 kHz, l'RC interno deriva sensibilmente. L'app deve riallineare
> l'orologio del dispositivo a ogni sync.

---

## 6. Ordine di implementazione consigliato

0. [ ] **Scrivere REGOUT0 = 3,0 V nell'UICR** (offset 0x304, valore `4`) e
       **verificare EXTSUPPLY = 1** (offset 0x300). Va fatto al primissimo flash:
       il default dell'nRF52840 su VDDH è 1,8 V, e a quella tensione la flash
       W25Q256JVEIQ (2,7-3,6 V) non funziona. Senza EXTSUPPLY dal pad `VDD` non
       si può prelevare corrente → IMU e flash restano morti. Vedi doc 02 §3.1
1. [ ] Bring-up: alimentazione, MCU vivo, LED lampeggia
2. [ ] SWD funzionante, **poi** DFU over BLE (prima del potting!)
3. [ ] Comunicazione SPI con IMU — leggere il registro WHO_AM_I
3b. [ ] Verificare che il quarzo Y1 a 32,768 kHz oscilli e sia selezionato come
        sorgente LFCLK (non l'RC interno)
4. [ ] Comunicazione SPI con flash — leggere il JEDEC ID
5. [ ] Misura del consumo reale in sleep → confronto col budget
6. [ ] FIFO + interrupt watermark
7. [ ] Scrittura su flash a blocchi
8. [ ] Dump via BLE
9. [ ] **→ Fase di raccolta dati (§3)**
10. [ ] **→ Sviluppo offline (§4)**
11. [ ] Porting dell'algoritmo congelato in C
12. [ ] App iOS + HealthKit
13. [ ] v2: rimozione flash, nuovo layout, potting

> Il punto 5 è un gate: se il consumo reale è molto sopra il budget, va capito
> **prima** di investire nell'algoritmo.

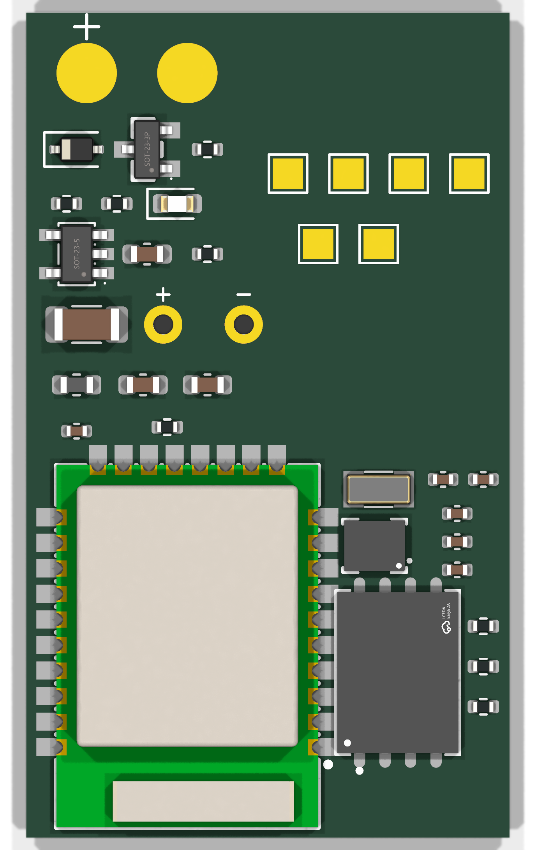
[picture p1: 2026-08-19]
hardware/production/anteprima-piazzamento.png

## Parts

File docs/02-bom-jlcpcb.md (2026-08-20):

# BOM e checklist JLCPCB

**Stato:** componenti verificati sul catalogo JLCPCB. ✅ = confermato in stock.
**Buona notizia trasversale:** tutte le righe hanno **Min: 1**. Nessun minimo
d'ordine forzato — il rischio di costo temuto non si è materializzato.

---

## 1. Tooling

| Cosa | Nota |
|---|---|
| KiCad | **9.0** — restare qui, non aggiornare a metà progetto |
| Plugin | **kicad-jlcpcb-tools** (Bouni) — repo custom, vedi §6 |
| Conversione parti | **easyeda2kicad** — genera simbolo/footprint/3D da codice LCSC |

---

## 2. BOM confermata

| Rif | Componente | LCSC | Package | Stock | Prezzo |
|---|---|---|---|---|---|
| U1 | **E73-2G4M08S1C** (Ebyte, nRF52840) | `C356849` | SMD 18×13 mm | 2437 ✅ | $8,14 |
| U2 | **LSM6DSV16XTR** (ST, IMU 6 assi) | `C5267406` | LGA-14 (2,5×3 mm) | ✅ | ~$2,88 |
| U3 | **W25Q256JVEIQ** (Winbond, 32 MB) | `C97522` | WSON-8-EP (6×8) | 16763 ✅ | €3,76 |
| U4 | **MCP73831T-2ATI/OT** (Microchip) | `C14879` | SOT-23-5 | 1957 ✅ | €0,96 |
| L1 | **MLZ1608M100WT000** (Murata, 10 µH, Isat 90 mA) | `C76798` | 0603 | 61743 ✅ | ~$0,02 |
| Y1 | **Q13FC13500004** (Epson, 32,768 kHz, CL 12,5 pF) | `C32346` | SMD3215-2P | 557062 ✅ **Basic** | ~$0,10 |
| C1, C2 | **18 pF ±5% C0G** (carico di Y1) | `C1549` | 0402 | 1306168 ✅ **Basic** | ~$0,002 |
| C_bulk | **47 µF 10 V** (serbatoio VDDH) | `C96123` | 1206 | 1054417 ✅ **Basic** | ~$0,03 |
| Q1 | **AO3401A** (P-MOSFET, blocco inversione) | `C15127` | SOT-23 | 545691 ✅ **Basic** | ~$0,03 |
| D1 | **PESD5V0S1BA** (TVS bidirezionale 5 V) | `C2827694` | SOD-323 | 1011482 ✅ | ~$0,01 |
| D2 | **LED rosso** | `C2286` | 0603 | 6043727 ✅ **Basic** | ~$0,004 |
| C4, C5, C10 | 4,7 µF 16 V X5R | `C19666` | 0603 | ✅ **Basic** | — |
| C6-C9 | 100 nF 16 V X7R | `C1525` | 0402 | ✅ **Basic** | — |
| R1-R4 | 10 kΩ (pull-up CS_IMU, CS_FLASH, WP#, HOLD#) | `C25744` | 0402 | ✅ **Basic** | — |
| R5, R8 | 100 kΩ (pull-up CHG_STAT, gate di Q1) | `C25741` | 0402 | ✅ **Basic** | — |
| R6 | 20 kΩ (ISET = 50 mA) | `C25765` | 0402 | ✅ **Basic** | — |
| R7 | 1 kΩ (serie LED) | `C11702` | 0402 | ✅ **Basic** | — |
| J1 | **piazzole di contatto** per il cavo magnetico — nessun componente | — | `PogoPads_2P_P5.0mm` | — | — |
| J2 | **piazzole di saldatura** per i fili della cella | — | `CellPads_2P_P4.0mm` | — | — |
| TP1-TP6 | pad di test (SWDIO, SWCLK, GND, +3V0, RESET, P0.04) | — | 1,5 × 1,5 mm | — | — |

**Righe Extended: 6** (U1, U2, U3, U4, L1, D1). Tutto il resto è Basic.

### 🔴 Piazzole invece di pogo pin — cambio rispetto al doc 01 §7

Il doc 01 prevede **pogo pin montati sul dispositivo**. I footprint disegnati
fanno l'opposto: sul dispositivo ci sono **piazzole piatte dorate**, e le molle
stanno sul cavo di ricarica.

**Perché:** un pogo pin è un pistone che si muove. Per montarlo servono un foro
nella capsula e una tenuta attorno a una parte mobile — cioè l'unico punto in cui
la resina non può sigillare niente, sul dispositivo che deve stare in piscina.
Con le piazzole la capsula non ha **nessuna apertura**: la resina si ferma a filo
del rame, e il rame è già dorato se si ordina la finitura **ENIG**.

Costo del cambio: il cavo di ricarica dev'essere del tipo "magnetico con puntali",
non un semplice cavo con contatti piatti.

- [ ] **Decisione da confermare.** Se preferisci i pogo pin sul dispositivo,
      il footprint va rifatto (30 minuti) e il doc 01 §7 resta com'è
- [ ] Il **passo di 5,0 mm** delle piazzole è un valore di partenza: va misurato
      sul cavo magnetico effettivamente acquistato, poi cambiato in
      `hardware/tools/gen_footprints.py` (una riga)
- [ ] Ordinare il PCB con finitura **ENIG**, non HASL: le piazzole di contatto
      sono strisciate mille volte e l'oro non si ossida

### Insieme da non montare in v2

La v2 toglie la flash e quello che serve solo a lei: **U3, R2, R3, R4, C9**.
Stesso layout, cinque righe marcate DNP. Nient'altro cambia.

### Stato dello schematico

Prima stesura generata da `hardware/tools/gen_schematic.py` e verificata:

- **ERC pulito, 0 violazioni** (`kicad-cli sch erc --severity-all`)
- 37 componenti, 26 reti, netlist controllata rete per rete
- I pin non usati del modulo hanno un **no-connect esplicito**, non sono
  semplicemente lasciati vuoti

> ⚠️ È uno schematico **"a netlist"**: i collegamenti sono etichette sui pin, non
> fili tirati a mano. È corretto ma non è leggibile come un disegno fatto bene.
> Va riordinato in Eeschema — e da quel momento **non rilanciare il generatore**,
> che riscrive il file da zero.

I tipi elettrici dei pin (`power_in`, `tri_state`, …) sono assegnati da
`hardware/tools/fix_pin_types.py`: easyeda2kicad li marca tutti `unspecified`, e
con quelli l'ERC non serve a niente. **Va rilanciato dopo ogni rigenerazione di
un simbolo con easyeda2kicad.**

### Stato del layout

Contorno, piazzamento, keepout e piani generati da `hardware/tools/gen_pcb.py`
e verificati con `kicad-cli pcb drc`:

- **0 errori.** Restano 7 avvisi `silk_over_copper` (contorni componente in
  serigrafia che toccano i pad): cosmetici, JLC taglia la serigrafia sui pad
- Keepout antenna su **tutti e 4 gli strati**, tutta la larghezza, da Y 37,4
- Impilaggio: `F.Cu` componenti, `In1.Cu` massa piena (è lo schermo sotto il
  modulo), `In2.Cu` +3V0 pieno, `B.Cu` libero per i segnali
- Sigle dei componenti su `F.Fab`, non in serigrafia: a 24 × 41 mm le scritte
  si sovrapporrebbero ai componenti
- **80 collegamenti da instradare**

### 🔴 L'instradamento automatico è stato tolto

`hardware/tools/route.py` contiene un instradatore scritto per questo progetto.
**Non funziona e non va usato** (`SEGNALI = False`, `VIE = False`).

Il motivo è concreto: l'IMU ha i pad a **passo 0,5 mm**, larghi 0,27 mm. Uscire
da lì richiede di posizionare le piste con precisione inferiore al passo della
griglia dell'instradatore. Con la griglia larga non passava niente; stringendo i
controlli i moncherini di uscita finivano sopra i pad vicini, e il DRC tirava
fuori **18 cortocircuiti veri** su 168 violazioni.

Meglio nessuna pista che piste sbagliate: le piazzole restano vergini e le piste
si tirano in **pcbnew con l'instradatore interattivo**, che il fan-out lo fa
bene e mostra il rats-nest mentre lavori.

Il codice resta nel repository perché la geometria (contorno, keepout, piani)
la genera lo stesso file, non perché l'instradamento vada ripreso.

### Note sui componenti

**U1 — E73-2G4M08S1C.** Sostituisce l'MDBT50Q-1MV2 (non disponibile).
Stesso chip nRF52840, modulo certificato con antenna integrata.

- ✅ **VDDH esposto** (pad `VDH` nel simbolo) → la scelta "LiPo diretta su VDDH"
  resta valida, nessun LDO da reintrodurre
- 🔴 **`DCH` esposto** → l'induttore di REG0 **non è integrato**, va aggiunto (L1)
- 🔴 **`XL1`/`XL2` esposti** → il quarzo 32,768 kHz **non è integrato** (Y1)
- ⚠️ **18 × 13 mm** → il PCB deve crescere (vedi doc 01 §7)
- ⚠️ **X-ray Inspection: Required** → costo aggiuntivo sull'ordine, **e il
  montaggio manuale del solo modulo non è più un'opzione**: ha pad sotto il
  corpo, non solo castellati

> Sigle lette dal simbolo EasyEDA: **confermare tutto sul datasheet Ebyte**
> (link "Download" nella pagina JLCPCB del componente).

**U2 — LSM6DSV16XTR** → `C5267406`, verificato nel catalogo PCBA di JLCPCB
(Extended, LGA-14 2,5×3 mm, MSL 1). "TR" = Tape & Reel, è solo il confezionamento.

> Esiste anche la riga `C42388605` ("LSM6DSV16X", New Arrivals, X-ray richiesta).
> È lo stesso chip: **usare `C5267406`**, e ricontrollare la scorta il giorno
> dell'ordine — la pagina JLC non espone lo stock senza login.

**U3 — W25Q256JVEIQ.** Variante 2,7-3,6 V, compatibile con il dominio a 3,0 V
scelto in §3. Solo v1.

> ⚠️ Se un giorno passassi al dominio a 1,8 V, questa parte **non funziona**.
> La variante corretta sarebbe `C2940048` (W25Q256JWEIQ, 1,7-1,95 V).

**U4 — MCP73831T-2ATI/OT.** Il "2" indica i 4,20 V corretti per LiPo.

- [ ] Aprire il PDF e verificare nella tabella di ordinazione che l'uscita STAT
      di questa variante sia leggibile da GPIO
- [ ] Alternativa se non lo è: `C424093` (`-2ACI/OT`, 2874 pz)
- [x] **Corrente di carica: verificata.** La 301220 scelta dichiara **carica
      max 1C = 80 mA**. I 50 mA di `R6 = 20 kΩ` sono **0,63C**: sotto il massimo
      e sopra i ~50 mA oltre i quali l'MCP73831 lavora con buona precisione.
      Ricarica completa in ~2 ore. Nessun cambio di componente

**L1 — induttore REG0.** Senza, REG0 resta in modalità LDO: scendere da 4,0 V a
3,0 V dissiperebbe il **25% su tutto il consumo della scheda**. Un componente
0603 vale il 25% di autonomia.

✅ **Valore confermato**: *nRF52840 PS*, §56.4 "Circuit configuration no. 4",
tabella 157 (designator L4): **10 µH, chip inductor, IDC min = 80 mA, ±10%,
0603**. Va **tra `DCH` (DCCH) e `VDD`**, cioè sull'uscita di REG0.

🔴 **Trappola: qui il componente Basic non si può usare.** L'unico 10 µH 0603
Basic in catalogo è `C1035` (Sunlord SDFL1608S100KTF) ed è un induttore *di
segnale*: **corrente nominale 3 mA**, DCR 1,85 Ω. Su un convertitore che deve
passare decine di mA satura e basta. Il campo "10 µH 0603" da solo non dice nulla:
va letta la corrente.

| LCSC | Modello | Tolleranza | Isat | I nom. | DCR | Lib |
|---|---|---|---|---|---|---|
| `C1035` | SDFL1608S100KTF | ±10% | — | **3 mA** ❌ | 1,85 Ω | Basic |
| **`C76798`** | **MLZ1608M100WT000** (Murata) | ±20% | **90 mA** ✅ | 250 mA | 1,05 Ω | Extended |
| `C87216` | LBMF1608T100K | ±10% | *non dichiarato* | 80 mA | 0,36 Ω | Extended |
| `C92970` | BRL1608T100M | ±20% | 170 mA | 170 mA | 2 Ω | Extended |

**Scelto `C76798`**: è l'unico che dichiara esplicitamente una **Isat (90 mA)
sopra gli 80 mA richiesti** da Nordic, con 61k pezzi a magazzino. La tolleranza
±20% non è un problema su un induttore di buck — Nordic stessa usa ±20% su L2
nella stessa tabella. `C87216` avrebbe la tolleranza giusta e un DCR migliore,
ma non pubblica la corrente di saturazione: è quella che conta.

**Y1 — quarzo 32,768 kHz.** Non strettamente obbligatorio, ma consigliato: senza,
l'RC interno richiede ricalibrazioni periodiche e **allarga le finestre di
ricezione BLE**, cioè consuma di più proprio dove stiamo ottimizzando. Costa
~2 µA e dà un orologio che non deriva tra una sync e l'altra.

✅ **Specifica confermata**. Il reference design Nordic (tabella 157, X2 + C16/C17)
usa un cristallo **CL 9 pF con due condensatori da 12 pF**; la tabella di specifica
LFXO (§17.4.3) ammette **CL fino a 12,5 pF**, C0 ≤ 2 pF, ESR ≤ 100 kΩ.

**Scelto `C32346`** (Epson Q13FC13500004, 32,768 kHz, ±20 ppm, **CL 12,5 pF**):
è l'unico 3215 **Basic** in catalogo, con 557k pezzi. Nessun costo di caricamento.

Condensatori di carico: dal reference design Nordic (9 pF con 12 pF) si ricava
una capacità parassita di **~3 pF** per ramo, quindi

`C = 2 × (CL − C_parassita) = 2 × (12,5 − 3) = 19 pF` → **18 pF (`C1549`, Basic)**

- [ ] Il valore parassita 3 pF è dedotto dal reference Nordic, non misurato:
      dipende dal layout. Con 18 pF l'errore residuo vale pochi ppm, e il BLE
      ne tollera ±250 → non è un rischio, ma va ricontrollato se un giorno
      servisse precisione d'orologio migliore
- Alternativa "copia esatta del reference": `C99010` (Epson CL 9 pF, Extended,
  45k pezzi) + 2 × `C1547` (12 pF). Costa una riga Extended in più e fa
  partire l'oscillatore un filo prima. Non vale la spesa

### Componenti NON assemblati da JLC (montaggio manuale)

- **Cella LiPo 301220**, 3,0 × 12 × 20 mm, 80 mAh dichiarati, **PCM integrato**,
  fili liberi. Confezione da 3 a ~10,4 € + spedizione (AliExpress, consegna
  ~2 mesi). La prima montata di solito si sacrifica: 3 pezzi sono il numero giusto
- Nessun pogo pin: sul dispositivo ci sono solo piazzole (vedi sopra)

---

## 3. 🔴 Decisione: dominio a 3,0 V

L'nRF52840 alimentato da VDDH ha REGOUT0 che **di default esce a 1,8 V**, e
questo definisce la tensione di tutta la scheda.

**Scelta: 3,0 V**, impostata scrivendo REGOUT0 nell'UICR al primo flash.

| | 3,0 V (scelto) | 1,8 V (default) |
|---|---|---|
| Flash | `C97522` standard | servirebbe `C2940048` |
| IMU | ✅ (1,71-3,6 V) | ✅ |
| LED | ✅ qualsiasi colore | ⚠️ solo rosso, a fatica |
| Programmatore | anche 3,3 V fissi | **VTref obbligatorio** |
| Consumo | leggermente superiore | leggermente inferiore |

Il guadagno energetico a 1,8 V è marginale rispetto al budget; la compatibilità
semplifica flash, LED e debugger.

**Conseguenza:** il vincolo sul programmatore si rilassa — un debugger economico
a 3,3 V fissi funziona. Il VTref resta preferibile ma non è bloccante.

### 3.1 Due registri UICR, non uno

| Registro | Offset | Valore | Nota |
|---|---|---|---|
| `REGOUT0` | 0x304 | `4` = 3,0 V | il default (`7`) è 1,8 V → **va scritto** |
| `EXTSUPPLY` | 0x300 | `1` = Enabled | consente di alimentare IMU e flash dal pad `VDD` |

`EXTSUPPLY` risulta già abilitato su UICR vergine (cancellata = tutti 1), ma va
**verificato dopo ogni `nrfjprog --eraseall`**: con `EXTSUPPLY = 0` dal pad `VDD`
non si può prelevare corrente, e IMU e flash restano senza alimentazione.

### 3.2 🔴 VEXDIF: il rail a 3,0 V non è garantito per tutta la scarica

*nRF52840 PS*, §16.10.1: **VEXDIF = 0,3 V minimo** — REG0 non può produrre una
tensione più vicina di 0,3 V al VDDH.

| VDDH (cella) | VDD (rail) | Stato |
|---|---|---|
| 4,2 → 3,3 V | 3,0 V | regolato |
| < 3,3 V | ≈ VDDH − 0,3 V | **il rail scende con la cella** |
| 3,0 V | ≈ 2,7 V | limite inferiore della flash W25Q256J**V** |

Non è bloccante — sotto i 3,3 V il degrado è graduale e tutto continua a
funzionare (IMU da 1,71 V, radio da 2,5 V su VDDH) — ma va saputo:

- La flash arriva **esattamente** al suo minimo (2,7 V) quando la cella è a 3,0 V.
  In v1, che scrive in flash, conviene fermare il logging sotto ~3,2 V di cella
- L'app deve mostrare "batteria scarica" intorno a 3,3 V, non a 3,0 V
- Altra voce da misurare in bring-up: `IEX,OFF` limita a **1 mA** la corrente
  prelevabile dal pad `VDD` in System OFF → flash in deep power-down obbligatoria

---

## 4. Basic vs Extended

JLCPCB divide i componenti in due categorie. I **Basic** sono già caricati sulle
macchine. Gli **Extended** richiedono caricamento manuale con **costo fisso per
tipo di componente**, indipendente dalla quantità.

Su un lotto da 5 pezzi questo domina il costo totale.

- Modulo, IMU e flash sono inevitabilmente Extended — sono loro il progetto
- [ ] **Tutti i passivi devono essere Basic**
- [ ] **Consolidare i valori**: se servono 47k, 51k e 56k in punti non critici,
      usarne uno solo per tutti e tre

---

## 5. Parametri di produzione

| Parametro | Scelta | Motivo |
|---|---|---|
| Dimensioni | **24 × 41 mm** | Disposizione corta e larga — vedi doc 01 §7 |
| Strati | 4 | — |
| Spessore | **0,8 mm** | Standard, stesso prezzo di 1,6. Guadagna ~1 mm nella capsula |
| Passivi | 0402 | Basic Parts + spazio |
| Assemblaggio | provare su una faccia sola | Il doppio lato costa di più e allunga i tempi |
| Separazione | **V-cut** dove la geometria lo consente | Le mouse bites lasciano sbavature, e la capsula deve incastrarsi con precisione |
| Ispezione | **X-ray obbligatoria** (richiesta dal modulo) | Costo aggiuntivo da mettere a preventivo |

---

## 6. Installazione plugin Bouni

Non è nel repository ufficiale KiCad. Va aggiunto a mano:

1. Plugin and Content Manager → **Gestisci...**
2. **➕** → incolla l'URL:
   `https://raw.githubusercontent.com/Bouni/bouni-kicad-repository/main/repository.json`
3. Nome: `Bouni` → salva
4. Seleziona il nuovo repository dalla tendina in alto
5. Installa **KiCad JLCPCB tools** → **Applica i cambiamenti**

> Se il repository non compare nella tendina, chiudi e riapri il Plugin Manager.

**Nota d'uso:** il plugin assegna i codici LCSC ai *footprint già piazzati sul
PCB*. Per la semplice verifica di disponibilità il sito jlcpcb.com è più rapido.

**Fabrication Toolkit** (bennymeg, nel repo ufficiale) è un'alternativa valida per
generare gerber/BOM/CPL, ma non cerca il catalogo da dentro KiCad.

---

## 7. Trappole note

### 🔴 Rotazioni nel file CPL

Errore numero uno dei primi ordini PCBA. JLCPCB usa convenzioni di orientamento
che spesso **non coincidono** con quelle delle librerie KiCad → componenti saldati
ruotati di 90°. Il plugin ha un **Rotation manager** con le correzioni note.

- [ ] **Controllare sempre l'anteprima grafica** che JLC mostra prima di confermare
- [ ] Verificare componente per componente dove sta il pin 1

### 🔴 Footprint del modulo radio

Usa **easyeda2kicad** con il codice `C356849` invece di disegnarlo a mano: genera
simbolo, footprint e modello 3D.

- [ ] **Verificare comunque il risultato contro il datasheet Ebyte**, in
      particolare il keepout d'antenna. È l'unica zona della scheda dove un
      errore non si recupera con un filo volante

### 🟡 Clearance dal bordo e pannellizzazione

JLC ha una distanza minima dei componenti dal bordo scheda. Il modulo che
"sporge oltre il bordo della batteria" è un requisito **meccanico dentro la
capsula**, non un componente a filo del bordo PCB.

- [ ] Verificare la regola di clearance prima di fissare l'outline
- [ ] Decidere V-cut vs mouse bites **prima** del layout

---

## 8. Ordine dei lavori

1. [x] Verificare i componenti sul catalogo JLCPCB
2. [x] Annotare il codice LCSC dell'LSM6DSV16XTR → `C5267406`
3. [x] Scaricare il datasheet Ebyte E73-2G4M08S1C → `docs/datasheet/`
4. [x] **Rifare la mappatura pin** (doc 01 §5) sul pinout Ebyte
5. [x] L1, Y1 e condensatori di carico scelti sul catalogo JLCPCB (§2)
6. [x] **Cella scelta e verificata: 301220**, 80 mAh, PCM integrato, carica
       max 1C (doc 01 §7)
7. [x] Generare simbolo e footprint con easyeda2kicad → `hardware/lib/`
8. [x] Schematico — prima stesura generata, ERC pulito; **da riordinare a mano**
9. [ ] Layout — [x] contorno, piazzamento, keepout e piani di massa generati;
       resta l'instradamento
10. [ ] Export BOM + CPL con il plugin
11. [ ] Controllo anteprima JLC pin per pin

---

## 9. Checklist pre-ordine

- [ ] DRC pulito
- [ ] ERC pulito
- [ ] Keepout antenna verificato su tutti e 4 gli strati (nessun rame, nessuna via)
- [ ] Induttore REG0 da 10 µH tra `DCH` e `VDD` (non tra `DCH` e `VDH`)
- [ ] Quarzo 32,768 kHz su `XL1`/`XL2` con i condensatori di carico
- [ ] Bulk 47 µF (`C96123`, 1206 10 V) vicino al VDDH del modulo
      *(il 47 µF 0805 da 6,3 V `C16780` perde molta più capacità per DC bias a 4,2 V)*
      *(la cella ha 1-2 Ω di resistenza interna; i picchi TX BLE la fanno affondare
      → brownout casuali durante la sync)*
- [ ] Resistore ISET calcolato per la corrente scelta
- [ ] TVS e protezione inversione sui pogo pin
      *(contatti esposti = ingresso preferito delle ESD; i pogo magnetici verranno
      attaccati al buio, storti, mille volte)*
- [ ] Pull-up su CS_IMU e CS_FLASH
- [ ] Pull-up su CHG_STAT
- [ ] Nessun segnale SPI su un pin "low frequency I/O only" (doc 01 §5.1)
- [ ] **4 pad SWD ben distanziati + punto di GND ampio**, accessibili prima del potting
- [ ] Modelli 3D verificati contro l'ingombro della capsula
- [ ] Anteprima JLC controllata pin 1 per pin 1

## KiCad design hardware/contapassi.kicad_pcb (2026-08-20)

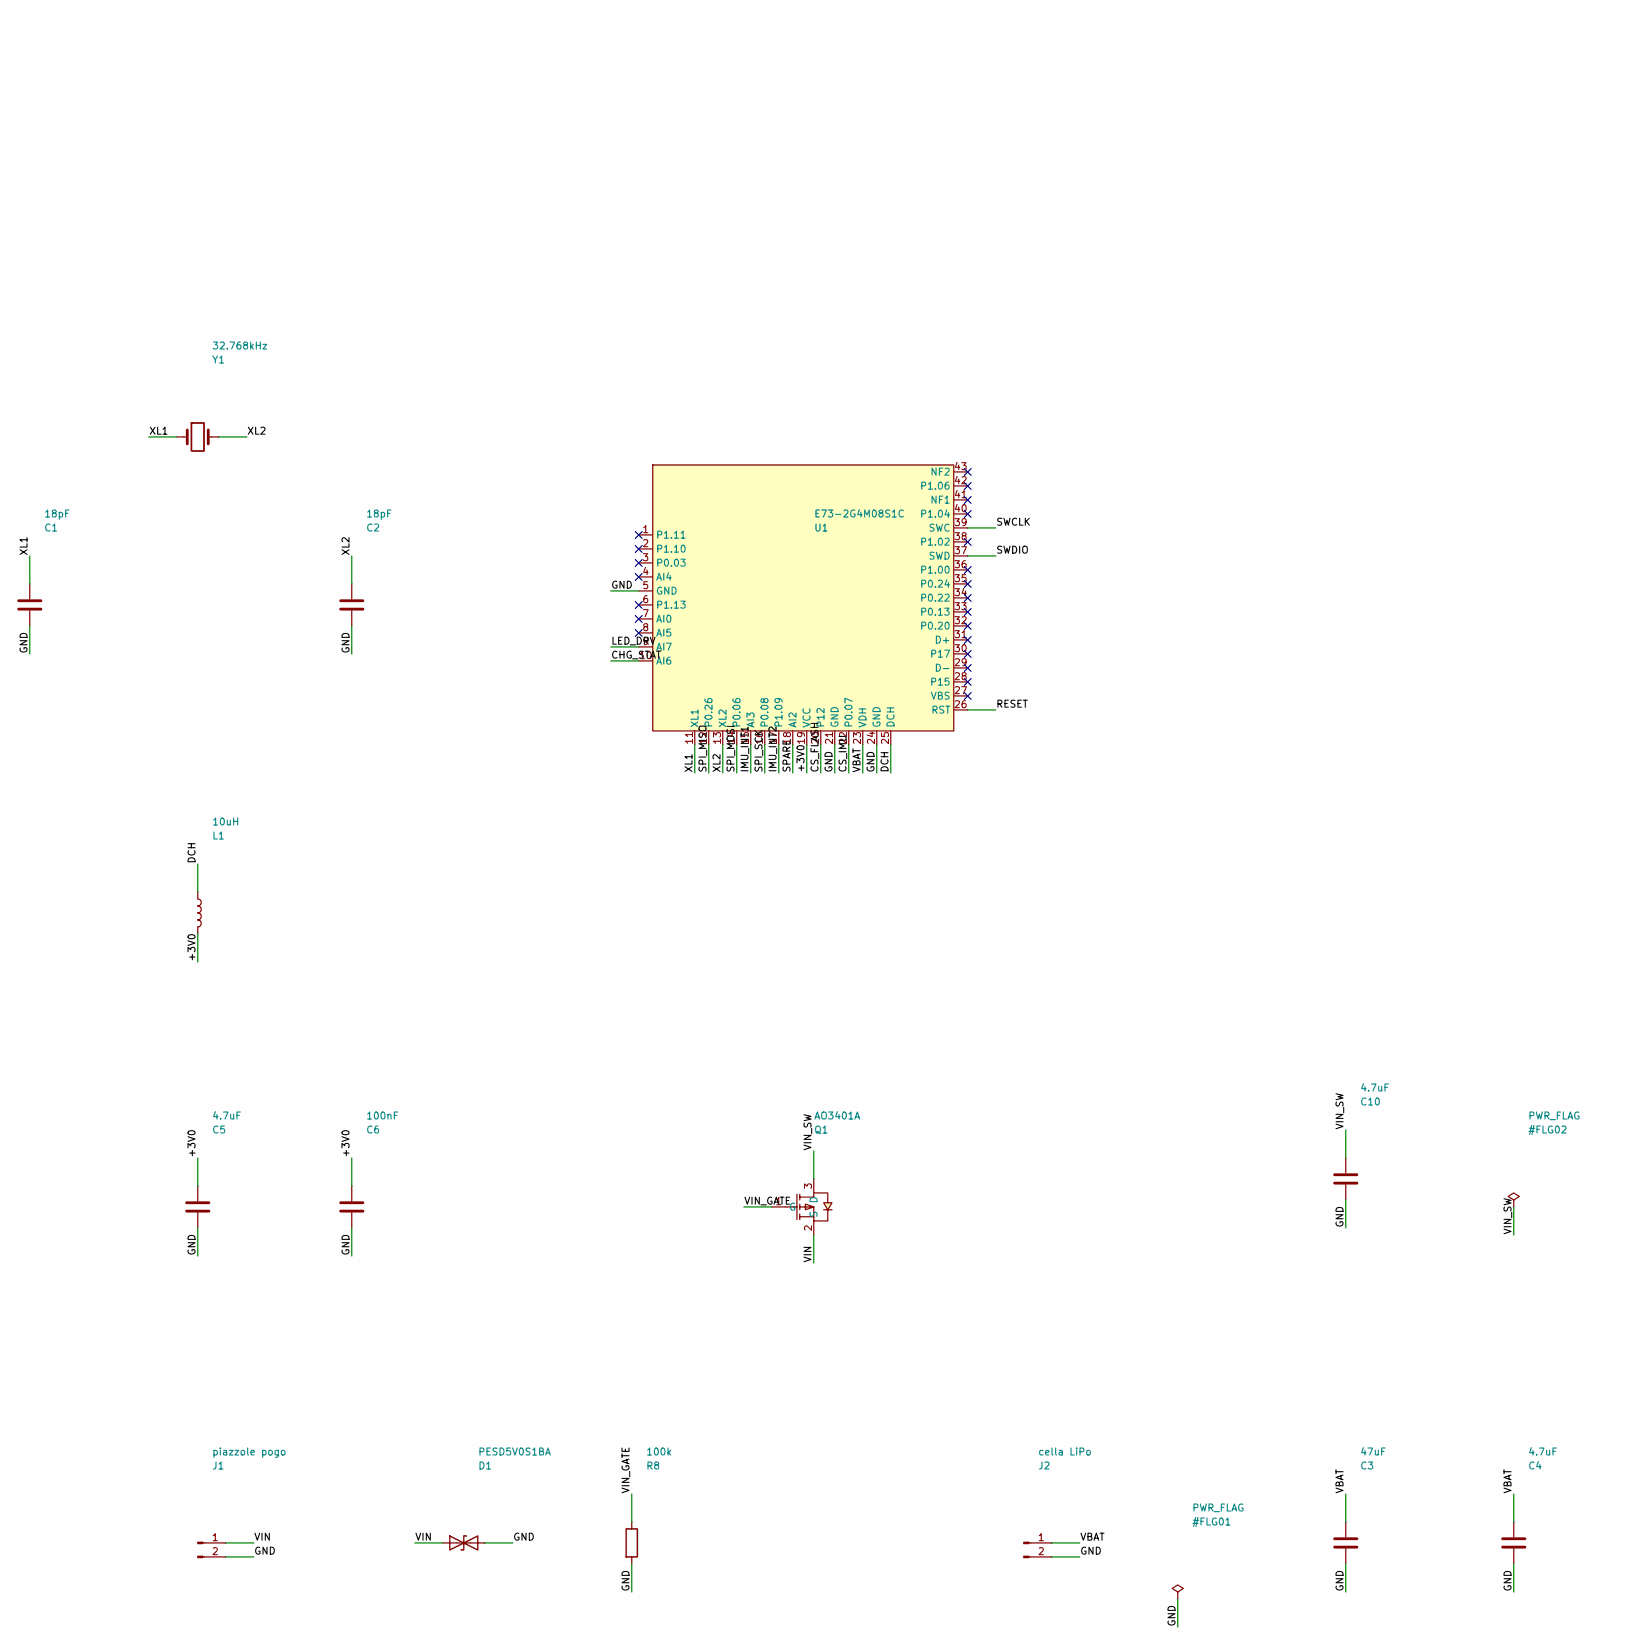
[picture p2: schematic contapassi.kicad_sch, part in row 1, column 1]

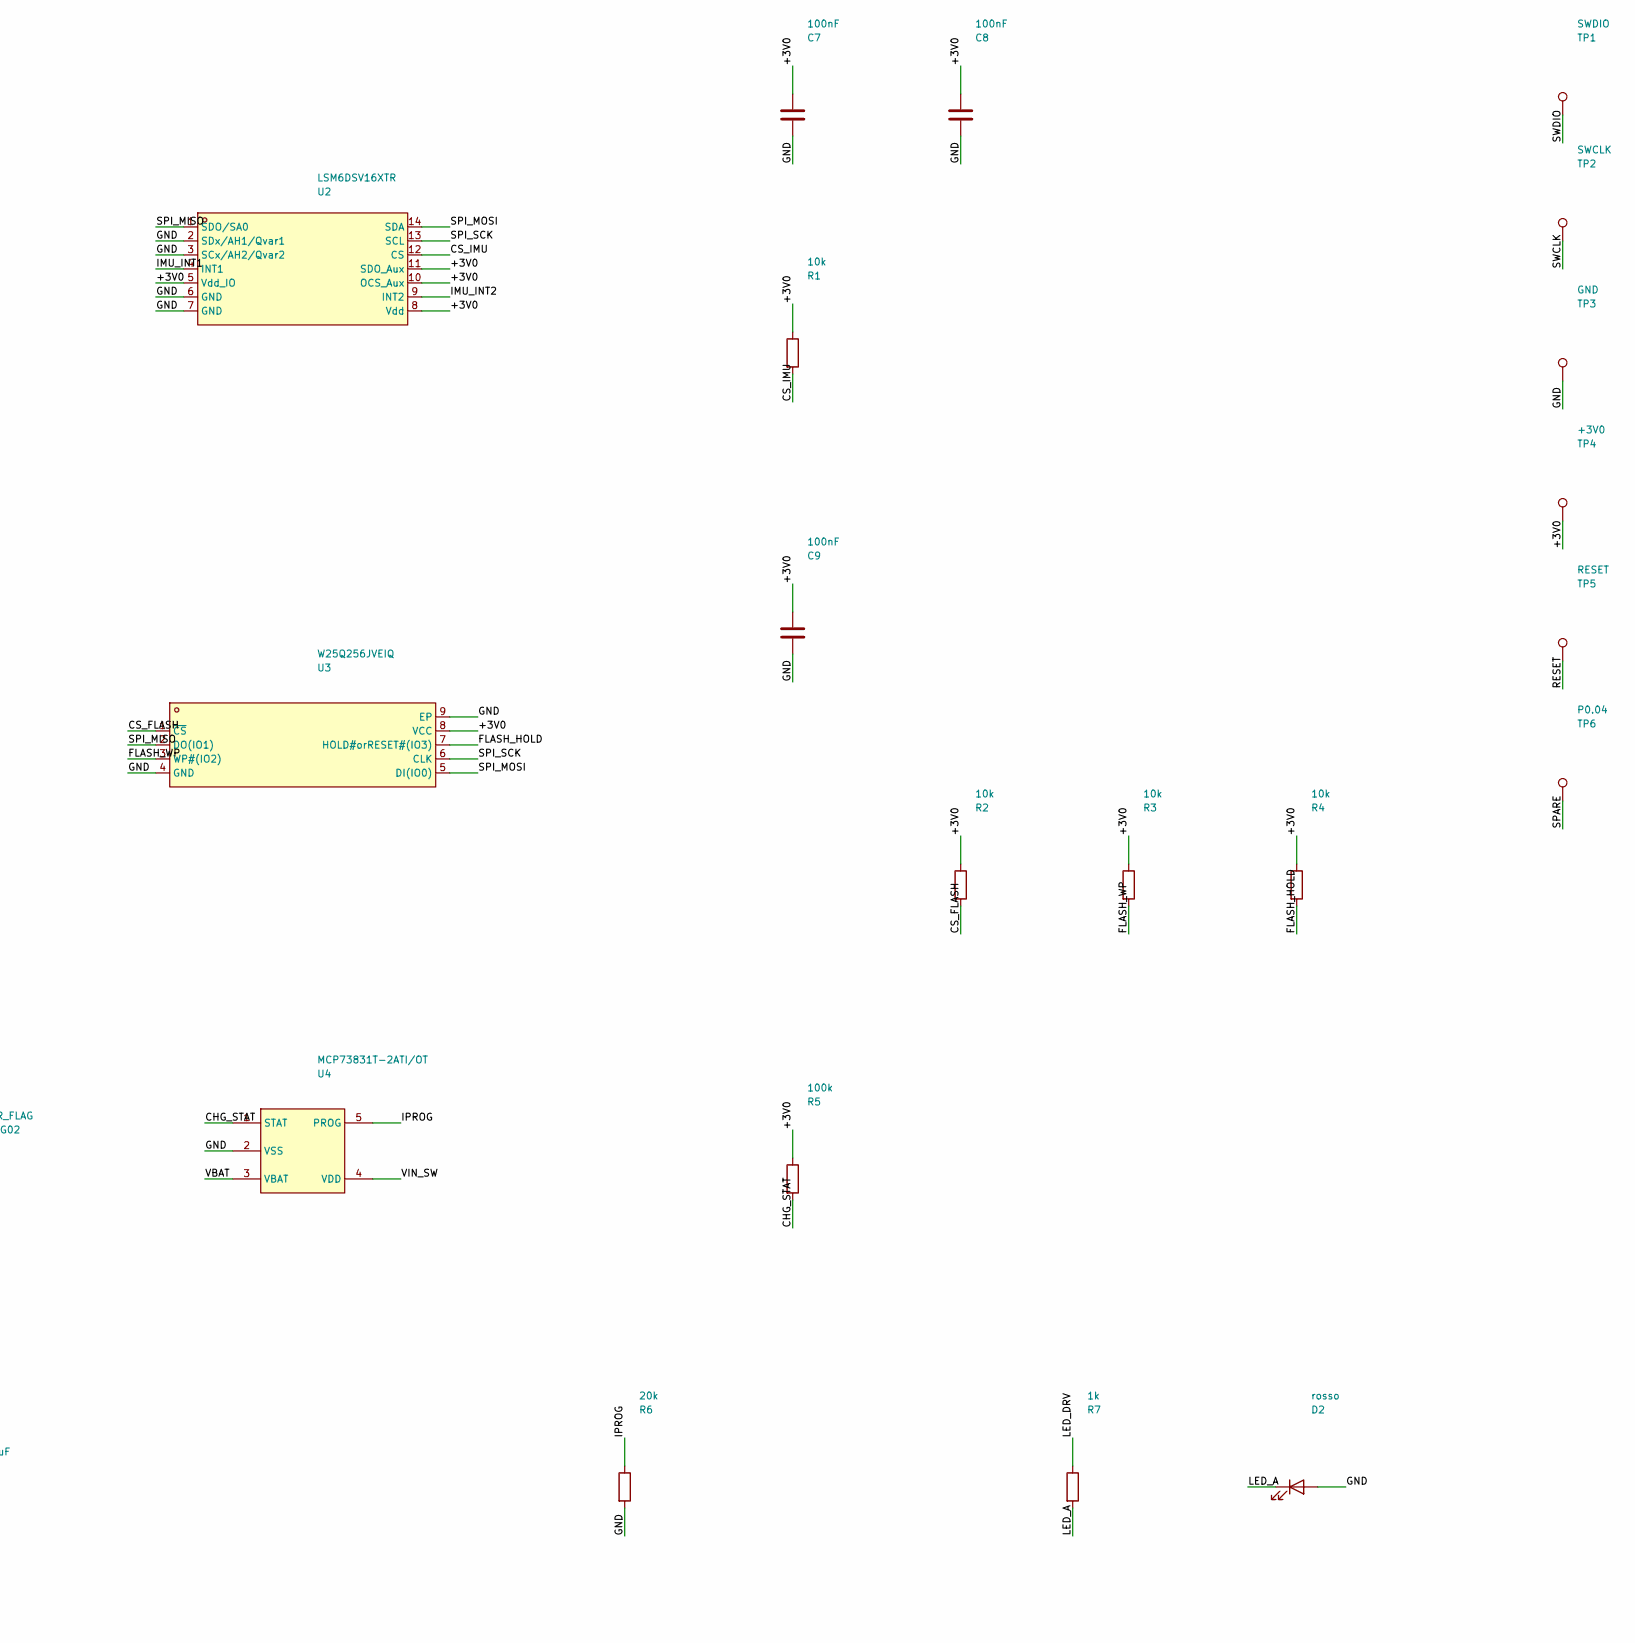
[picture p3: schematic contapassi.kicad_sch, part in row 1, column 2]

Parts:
C1, C2: 18pF; C_0402_1005Metric; LCSC C1549
C3: 47uF; C_1206_3216Metric; LCSC C96123
C4, C5, C10: 4.7uF; C_0603_1608Metric; LCSC C19666
C6, C7, C8, C9: 100nF; C_0402_1005Metric; LCSC C1525
D1: PESD5V0S1BA; D_SOD-323; LCSC C2827694
D2: rosso; LED_0603_1608Metric; LCSC C2286
J1: piazzole pogo; PogoPads_2P_P5.0mm
J2: cella LiPo; CellPads_2P_P4.0mm
L1: 10uH; L_0603_1608Metric; LCSC C76798
Q1: AO3401A; SOT-23_L2.9-W1.3-P1.90-LS2.4-BR; LCSC C15127
R1, R2, R3, R4: 10k; R_0402_1005Metric; LCSC C25744
R5, R8: 100k; R_0402_1005Metric; LCSC C25741
R6: 20k; R_0402_1005Metric; LCSC C25765
R7: 1k; R_0402_1005Metric; LCSC C11702
TP1: SWDIO; TestPoint_Pad_1.5x1.5mm
TP2: SWCLK; TestPoint_Pad_1.5x1.5mm
TP3: GND; TestPoint_Pad_1.5x1.5mm
TP4: +3V0; TestPoint_Pad_1.5x1.5mm
TP5: RESET; TestPoint_Pad_1.5x1.5mm
TP6: P0.04; TestPoint_Pad_1.5x1.5mm
U1: E73-2G4M08S1C; WIRELM-SMD_E73-2G4M08S1C; LCSC C356849
U2: LSM6DSV16XTR; LGA-14_L3.0-W2.5-P0.50-BR; LCSC C5267406
U3: W25Q256JVEIQ; WSON-8_L8.0-W6.10-P1.27-BL-EP; LCSC C97522
U4: MCP73831T-2ATI/OT; SOT-23-5_L3.0-W1.7-P0.95-LS2.8-BR; LCSC C14879
Y1: 32.768kHz; Crystal_SMD_3215-2Pin_3.2x1.5mm; LCSC C32346

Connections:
+3V0: C5.1, C6.1, C7.1, C8.1, C9.1, L1.2, R1.1, R2.1, R3.1, R4.1, R5.1, TP4.1, U1.19 (VCC), U2.5 (Vdd_IO), U2.8 (Vdd), U2.10 (OCS_Aux), U2.11 (SDO_Aux), U3.8 (VCC)
CHG_STAT: R5.2, U1.10 (AI6), U4.1 (STAT)
CS_FLASH: R2.2, U1.20 (P12), U3.1 (~CS)
CS_IMU: R1.2, U1.22 (P0.07), U2.12 (CS)
DCH: L1.1, U1.25 (DCH)
FLASH_HOLD: R4.2, U3.7 (HOLD#orRESET#(IO3))
FLASH_WP: R3.2, U3.3 (WP#(IO2))
GND: C1.2, C2.2, C3.2, C4.2, C5.2, C6.2, C7.2, C8.2, C9.2, C10.2, D1.2 (A2), D2.2 (A), J1.2, J2.2, R6.2, R8.2, TP3.1, U1.5 (GND), U1.21 (GND), U1.24 (GND), U2.2 (SDx/AH1/Qvar1), U2.3 (SCx/AH2/Qvar2), U2.6 (GND), U2.7 (GND), U3.4 (GND), U3.9 (EP), U4.2 (VSS)
IMU_INT1: U1.15 (AI3), U2.4 (INT1)
IMU_INT2: U1.17 (P1.09), U2.9 (INT2)
IPROG: R6.1, U4.5 (PROG)
LED_A: D2.1 (K), R7.2
LED_DRV: R7.1, U1.9 (AI7)
RESET: TP5.1, U1.26 (RST)
SPARE: TP6.1, U1.18 (AI2)
SPI_MISO: U1.12 (P0.26), U2.1 (SDO/SA0), U3.2 (DO(IO1))
SPI_MOSI: U1.14 (P0.06), U2.14 (SDA), U3.5 (DI(IO0))
SPI_SCK: U1.16 (P0.08), U2.13 (SCL), U3.6 (CLK)
SWCLK: TP2.1, U1.39 (SWC)
SWDIO: TP1.1, U1.37 (SWD)
VBAT: C3.1, C4.1, J2.1, U1.23 (VDH), U4.3 (VBAT)
VIN: D1.1 (A1), J1.1, Q1.2 (S)
VIN_GATE: Q1.1 (G), R8.1
VIN_SW: C10.1, Q1.3 (D), U4.4 (VDD)
XL1: C1.1, U1.11 (XL1), Y1.1
XL2: C2.1, U1.13 (XL2), Y1.2

Board: 4 copper layers, 35 parts (0 on the bottom side), 26 nets, no tracks yet.

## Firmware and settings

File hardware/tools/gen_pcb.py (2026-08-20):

#!/usr/bin/env python3
"""Genera la prima stesura del PCB: contorno, piazzamento, keepout, piani di massa.

Non instrada niente: le piste si tirano a mano in pcbnew. Qui c'e' la geometria,
che e' la parte dove un errore costa un giro di produzione.

La netlist arriva da gen_schematic.COMPONENTS: unica fonte, mai riscritta a mano.

Disposizione "corta e larga" (doc 01 §7), scheda 24 x 41 mm, origine in alto a
sinistra, Y crescente verso il basso:

    Y 0-21   zona cella   cella 12 x 20 sotto, a destra (X 11-23)
                          a sinistra (X 1-10) resta libero: carica e alimentazione
    Y 22-40  zona modulo  modulo a sinistra (X 1-14), striscia componenti a destra
    Y 38-41  ANTENNA      keepout su tutti gli strati, tutta la larghezza

    python hardware/tools/gen_pcb.py
"""
import os
import re
import sys
import uuid

HERE = os.path.dirname(os.path.abspath(__file__))
HW = os.path.dirname(HERE)
KI_FP = r"C:\Program Files\KiCad\9.0\share\kicad\footprints"
OUT = os.path.join(HW, "contapassi.kicad_pcb")

sys.path.insert(0, HERE)
from gen_schematic import COMPONENTS  # noqa: E402
import route as router  # noqa: E402

# ------------------------------------------------------------------ geometria
OFF_X, OFF_Y = 100.0, 60.0     # posizione della scheda sul foglio
BW, BH = 24.0, 41.0            # scheda: larghezza x lunghezza
ANT_Y = 37.4                   # oltre questa Y c'e' l'antenna: niente rame
CELL = (11.0, 1.0, 23.0, 21.0) # ingombro cella sul retro (x1, y1, x2, y2)

# ref -> (x, y) in coordinate scheda. Tutto a rotazione 0: ruotare in pcbnew
# se serve, cosi' il file resta semplice e verificabile.
PLACEMENT = {
    # --- zona modulo: modulo a sinistra, striscia componenti a destra -------
    "U1": (8.0, 29.5),     # modulo: antenna verso Y alta, y 22,5-40,5
    "Y1": (17.5, 23.7),    # quarzo, vicino a XL1/XL2 (pad a X 11,2-12,5 / Y 22,5)
    "C1": (20.7, 23.2),
    "C2": (22.7, 23.2),
    "U2": (17.3, 26.5),    # IMU, vicino ai pad SPI del modulo
    "C7": (21.4, 24.9),
    "C8": (21.4, 26.3),
    "C9": (21.4, 27.7),
    "U3": (18.45, 32.8),   # flash 6x8: il pezzo piu' grande della striscia
    "R2": (22.7, 30.5),
    "R3": (22.7, 32.5),
    "R4": (22.7, 34.5),
    # --- zona cella, meta' sinistra libera: carica e alimentazione ----------
    "J1": (5.5, 3.0),      # piazzole pogo, estremita' opposta all'antenna
    "D1": (2.5, 6.8),
    "Q1": (6.0, 6.8),
    "R8": (9.0, 6.8),
    "R5": (2.0, 9.5),
    "R7": (4.5, 9.5),
    "D2": (7.5, 9.5),
    "U4": (2.5, 12.0),
    "C10": (6.0, 12.0),
    "R6": (9.0, 12.0),
    "C3": (3.0, 15.5),     # bulk 47 uF
    "J2": (8.8, 15.5),     # fori per i fili: entrambi FUORI dall'ingombro cella
    "L1": (2.5, 18.5),     # induttore REG0: il piu' vicino possibile a DCH
    "C4": (5.8, 18.5),
    "C5": (9.0, 18.5),
    "C6": (2.5, 20.8),
    "R1": (7.0, 20.6),     # pull-up CS_IMU: sta bene ovunque
    # --- pad di test: solo rame, possono stare sopra la cella --------------
    "TP1": (13.0, 8.0),
    "TP2": (16.0, 8.0),
    "TP3": (19.0, 8.0),
    "TP4": (22.0, 8.0),
    "TP5": (14.5, 11.5),
    "TP6": (17.5, 11.5),
}

# Pad senza numero: le via termiche dentro l'exposed pad della flash. Vanno
# alla stessa rete dell'EP, altrimenti il DRC le vede come rame scollegato.
EXTRA_PAD_NETS = {"U3": {"": "GND"}}

FP_DIRS = [os.path.join(HW, "lib", "contapassi.pretty")] + [
    os.path.join(KI_FP, d) for d in os.listdir(KI_FP) if d.endswith(".pretty")
]


def uid():
    return str(uuid.uuid4())


def find_fp(lib_id):
    lib, name = lib_id.split(":", 1)
    for d in FP_DIRS:
        if os.path.basename(d) == lib + ".pretty":
            p = os.path.join(d, name + ".kicad_mod")
            if os.path.exists(p):
                return open(p, encoding="utf-8").read()
    raise FileNotFoundError(lib_id)


def strip_head(txt, lib_id):
    """Toglie version/generator/generator_version: dentro il .kicad_pcb non vanno."""
    txt = re.sub(r'\(footprint\s+"[^"]+"', '(footprint "%s"' % lib_id, txt, count=1)
    for tag in ("version", "generator_version", "generator"):
        txt = re.sub(r'\n\s*\(%s [^)]*\)' % tag, "", txt, count=1)
    return txt


PAD_RE = re.compile(
    r'\(pad\s+"([^"]*)"\s+(smd|thru_hole|np_thru_hole)\s+\w+'
    r'[\s\S]*?\(at\s+([-\d.]+)\s+([-\d.]+)(?:\s+([-\d.]+))?\)'
    r'[\s\S]*?\(size\s+([\d.]+)\s+([\d.]+)\)')


def pads_of(txt, x0, y0, nets):
    """Pad in coordinate scheda: posizione, ingombro, rete, foro passante."""
    out = []
    for m in PAD_RE.finditer(txt):
        num, kind, px, py, rot, w, h = m.groups()
        w, h = float(w), float(h)
        if rot and int(float(rot)) % 180 == 90:
            w, h = h, w
        net = nets.get(num)
        if not net:
            continue
        out.append({"num": num, "x": x0 + float(px), "y": y0 + float(py),
                    "w": w, "h": h, "net": net, "th": kind != "smd"})
    return out


def set_pad_nets(txt, nets_by_pad):
    """Aggiunge (net n "nome") a ogni pad che ha una rete."""
    out = []
    i = 0
    for m in re.finditer(r'\(pad\s+"([^"]*)"\s', txt):
        num = m.group(1)
        # fine del blocco pad
        depth = 0
        j = m.start()
        while True:
            if txt[j] == "(":
                depth += 1
            elif txt[j] == ")":
                depth -= 1
                if depth == 0:
                    break
            j += 1
        blk = txt[m.start():j]
        if num in nets_by_pad:
            code, name = nets_by_pad[num]
            blk += '\n\t\t(net %d "%s")' % (code, name)
        out.append(txt[i:m.start()])
        out.append(blk)
        i = j
    out.append(txt[i:])
    return "".join(out)


LAYERS = """\t(layers
\t\t(0 "F.Cu" signal)
\t\t(1 "In1.Cu" signal "GND")
\t\t(2 "In2.Cu" signal)
\t\t(31 "B.Cu" signal)
\t\t(32 "B.Adhes" user "B.Adhesive")
\t\t(33 "F.Adhes" user "F.Adhesive")
\t\t(34 "B.Paste" user)
\t\t(35 "F.Paste" user)
\t\t(36 "B.SilkS" user "B.Silkscreen")
\t\t(37 "F.SilkS" user "F.Silkscreen")
\t\t(38 "B.Mask" user)
\t\t(39 "F.Mask" user)
\t\t(40 "Dwgs.User" user "User.Drawings")
\t\t(41 "Cmts.User" user "User.Comments")
\t\t(42 "Eco1.User" user "User.Eco1")
\t\t(43 "Eco2.User" user "User.Eco2")
\t\t(44 "Edge.Cuts" user)
\t\t(45 "Margin" user)
\t\t(46 "B.CrtYd" user "B.Courtyard")
\t\t(47 "F.CrtYd" user "F.Courtyard")
\t\t(48 "B.Fab" user)
\t\t(49 "F.Fab" user)
\t)
"""

SETUP = """\t(setup
\t\t(pad_to_mask_clearance 0)
\t\t(allow_soldermask_bridges_in_footprints yes)
\t\t(pcbplotparams
\t\t\t(layerselection 0x00000000_00000000_55555555_5755f5ff)
\t\t\t(plot_on_all_layers_selection 0x0000000_00000000_00000000_00000000)
\t\t\t(disableapertmacros no) (usegerberextensions no) (usegerberattributes yes)
\t\t\t(usegerberadvancedattributes yes) (creategerberjobfile yes)
\t\t\t(dashed_line_dash_ratio 12.000000) (dashed_line_gap_ratio 3.000000)
\t\t\t(svgprecision 4) (plotframeref no) (mode 1) (useauxorigin no)
\t\t\t(dxfpolygonmode yes) (dxfimperialunits yes) (dxfusepcbnewfont yes)
\t\t\t(psnegative no) (psa4output no) (plot_black_and_white yes)
\t\t\t(sketchpadsonfab no) (plotpadnumbers no) (hidednponfab no)
\t\t\t(sketchdnponfab yes) (crossoutdnponfab yes) (subtractmaskfromsilk no)
\t\t\t(outputformat 1) (mirror no) (drillshape 1) (scaleselection 1)
\t\t\t(outputdirectory "")
\t\t)
\t)
"""


def line(x1, y1, x2, y2, layer, width=0.1):
    return ('\t(gr_line (start %.3f %.3f) (end %.3f %.3f)\n'
            '\t\t(stroke (width %.3f) (type solid)) (layer "%s") (uuid "%s")\n\t)\n'
            % (OFF_X + x1, OFF_Y + y1, OFF_X + x2, OFF_Y + y2, width, layer, uid()))


def poly(pts):
    return "\t\t\t(pts\n" + "".join(
        "\t\t\t\t(xy %.3f %.3f)\n" % (OFF_X + x, OFF_Y + y) for x, y in pts) + "\t\t\t)\n"


def keepout(name, pts, layers, pads="allowed", footprints="allowed"):
    """Area vietata. I pad del modulo stesso stanno per forza dentro l'area
    dell'antenna: quello che va vietato sono piste, via e riempimenti."""
    return ('\t(zone\n\t\t(net 0)\n\t\t(net_name "")\n\t\t(layers %s)\n'
            '\t\t(uuid "%s")\n\t\t(name "%s")\n\t\t(hatch edge 0.5)\n'
            '\t\t(connect_pads (clearance 0))\n\t\t(min_thickness 0.25)\n'
            '\t\t(filled_areas_thickness no)\n'
            '\t\t(keepout (tracks not_allowed) (vias not_allowed) (pads %s)\n'
            '\t\t\t(copperpour not_allowed) (footprints %s))\n'
            '\t\t(fill (thermal_gap 0.5) (thermal_bridge_width 0.5))\n'
            '\t\t(polygon\n%s\t\t)\n\t)\n'
            % (" ".join('"%s"' % l for l in layers), uid(), name,
               pads, footprints, poly(pts)))


def plane(layer, code, name, pts):
    return ('\t(zone\n\t\t(net %d)\n\t\t(net_name "%s")\n\t\t(layer "%s")\n'
            '\t\t(uuid "%s")\n\t\t(name "%s %s")\n\t\t(hatch edge 0.5)\n'
            '\t\t(connect_pads (clearance 0.2))\n\t\t(min_thickness 0.25)\n'
            '\t\t(filled_areas_thickness no)\n'
            '\t\t(fill yes (thermal_gap 0.3) (thermal_bridge_width 0.3))\n'
            '\t\t(polygon\n%s\t\t)\n\t)\n'
            % (code, name, layer, uid(), name, layer, poly(pts)))


def seg(x1, y1, x2, y2, layer, code):
    return ('\t(segment (start %.3f %.3f) (end %.3f %.3f) (width %.2f)'
            ' (layer "%s") (net %d) (uuid "%s"))\n'
            % (OFF_X + x1, OFF_Y + y1, OFF_X + x2, OFF_Y + y2,
               router.TRACK_W, layer, code, uid()))


def via(x, y, code):
    return ('\t(via (at %.3f %.3f) (size %.2f) (drill %.2f)'
            ' (layers "F.Cu" "B.Cu") (net %d) (uuid "%s"))\n'
            % (OFF_X + x, OFF_Y + y, router.VIA_DIA, router.VIA_DRILL,
               code, uid()))


def main():
    # ---- reti ------------------------------------------------------------
    names = sorted({n for c in COMPONENTS for n in c[6].values()})
    code = {n: i + 1 for i, n in enumerate(names)}
    nets = '\t(net 0 "")\n' + "".join(
        '\t(net %d "%s")\n' % (code[n], n) for n in names)

    # ---- footprint -------------------------------------------------------
    body = []
    mancanti = []
    tutti_pad = []
    for ref, lib_id, val, fp, lcsc, at, pinnets in COMPONENTS:
        if ref.startswith("#"):
            continue
        if ref not in PLACEMENT:
            mancanti.append(ref)
            continue
        x, y = PLACEMENT[ref]
        txt = strip_head(find_fp(fp), fp)
        pn = {p: (code[n], n) for p, n in pinnets.items()}
        # pad senza numero (via termiche nell'exposed pad): stessa rete dell'EP
        for p, n in EXTRA_PAD_NETS.get(ref, {}).items():
            pn[p] = (code[n], n)
        txt = set_pad_nets(txt, pn)
        # riferimento, valore, posizione
        txt = re.sub(r'\(property "Reference" "[^"]*"', '(property "Reference" "%s"' % ref, txt, count=1)
        # sigle sul lato fabbricazione, non in serigrafia: la scheda e' troppo
        # piccola perche' le scritte non si sovrappongano ai componenti
        txt = re.sub(r'(\(property "Reference"[\s\S]{0,120}?\(layer ")F\.SilkS(")',
                     r'\1F.Fab\2', txt, count=1)
        txt = re.sub(r'\(property "Value" "[^"]*"', '(property "Value" "%s"' % val, txt, count=1)
        head = '(footprint "%s"\n\t\t(layer "F.Cu")\n\t\t(uuid "%s")\n\t\t(at %.3f %.3f)' % (
            fp, uid(), OFF_X + x, OFF_Y + y)
        txt = re.sub(r'\(footprint "[^"]*"\n?\s*\(layer "[^"]*"\)', head, txt, count=1)
        if not txt.startswith("(footprint"):
            raise ValueError(ref)
        body.append("\t" + txt.strip() + "\n")
        tutti_pad.extend(pads_of(txt, x, y, {p: n for p, n in pinnets.items()}))

    # ---- contorno --------------------------------------------------------
    edge = "".join([line(0, 0, BW, 0, "Edge.Cuts"), line(BW, 0, BW, BH, "Edge.Cuts"),
                    line(BW, BH, 0, BH, "Edge.Cuts"), line(0, BH, 0, 0, "Edge.Cuts")])

    # ---- ingombro cella, disegnato per riferimento -----------------------
    x1, y1, x2, y2 = CELL
    edge += "".join([line(x1, y1, x2, y1, "Dwgs.User", 0.15),
                     line(x2, y1, x2, y2, "Dwgs.User", 0.15),
                     line(x2, y2, x1, y2, "Dwgs.User", 0.15),
                     line(x1, y2, x1, y1, "Dwgs.User", 0.15)])

    # ---- keepout antenna: tutti gli strati, tutta la larghezza -----------
    ko = keepout("keepout antenna E73",
                 [(-0.2, ANT_Y), (BW + 0.2, ANT_Y), (BW + 0.2, BH + 0.2), (-0.2, BH + 0.2)],
                 ["F.Cu", "In1.Cu", "In2.Cu", "B.Cu"])
    # ---- ingombro cella: niente componenti sul retro sotto la cella -------
    ko += keepout("ingombro cella LiPo",
                  [(x1, y1), (x2, y1), (x2, y2), (x1, y2)], ["B.Cu"],
                  pads="allowed", footprints="not_allowed")

    # ---- piani: In1 massa (schermo sotto il modulo), In2 alimentazione ----
    board = [(0.6, 0.6), (BW - 0.6, 0.6), (BW - 0.6, BH - 0.6), (0.6, BH - 0.6)]
    zones = (plane("In1.Cu", code["GND"], "GND", board)
             + plane("In2.Cu", code["+3V0"], "+3V0", board))

    # ---- instradamento ----------------------------------------------------
    f_seg, b_seg, vias, aperte = router.route(tutti_pad, BW, BH, ANT_Y)
    tracks = "".join(
        seg(a, b, c, d, "F.Cu", code[n]) for a, b, c, d, n in f_seg)
    tracks += "".join(
        seg(a, b, c, d, "B.Cu", code[n]) for a, b, c, d, n in b_seg)
    tracks += "".join(via(x, y, code[n]) for x, y, n in vias)

    out = ('(kicad_pcb\n\t(version 20241229)\n\t(generator "contapassi/gen_pcb.py")\n'
           '\t(generator_version "9.0")\n'
           '\t(general\n\t\t(thickness 0.8)\n\t\t(legacy_teardrops no)\n\t)\n'
           '\t(paper "A4")\n' + LAYERS + SETUP + nets
           + "".join(body) + edge + ko + tracks + zones + ')\n')
    open(OUT, "w", encoding="utf-8").write(out)
    print("scritto %s" % OUT)
    print("scheda %.0f x %.0f mm, %d footprint, %d reti"
          % (BW, BH, len(body), len(names)))
    print("instradamento: %d via, %d tratti su B.Cu, %d moncherini su F.Cu"
          % (len(vias), len(b_seg), len(f_seg)))
    if aperte:
        print("NON INSTRADATE (%d):" % len(aperte))
        for n, a, b in aperte:
            print("   %-12s (%.1f,%.1f) -> (%.1f,%.1f)" % (n, a[0], a[1], b[0], b[1]))
    if mancanti:
        print("SENZA POSIZIONE: %s" % ", ".join(mancanti))


if __name__ == "__main__":
    main()

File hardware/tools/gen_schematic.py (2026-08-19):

#!/usr/bin/env python3
"""Genera la prima stesura dello schematico contapassi (KiCad 9).

Le connessioni sono espresse per NOME DI RETE: ogni pin collegato riceve uno
stub e un'etichetta. Uno schematico "a netlist", pensato per essere corretto e
verificabile con `kicad-cli sch erc`, non per essere bello. Dopo averlo
riordinato a mano in Eeschema NON rilanciare questo script: sovrascrive il file.

    python hardware/tools/gen_schematic.py
"""
import os
import re
import uuid

HERE = os.path.dirname(os.path.abspath(__file__))
HW = os.path.dirname(HERE)
KI = r"C:\Program Files\KiCad\9.0\share\kicad\symbols"
OUT = os.path.join(HW, "contapassi.kicad_sch")

LIBS = {
    "Device": os.path.join(KI, "Device.kicad_sym"),
    "Connector": os.path.join(KI, "Connector.kicad_sym"),
    "power": os.path.join(KI, "power.kicad_sym"),
    "contapassi": os.path.join(HW, "lib", "contapassi.kicad_sym"),
}

DQ = chr(34)


# ---------------------------------------------------------------- s-expression
def find_block(text, name):
    """Testo del blocco (symbol "name" ...), bilanciando le parentesi."""
    m = re.search(r"\(symbol\s+" + DQ + re.escape(name) + DQ, text)
    if not m:
        raise KeyError(name)
    i = m.start()
    depth = 0
    instr = False
    esc = False
    for j in range(i, len(text)):
        ch = text[j]
        if esc:
            esc = False
            continue
        if ch == "\\":
            esc = True
            continue
        if ch == DQ:
            instr = not instr
            continue
        if instr:
            continue
        if ch == "(":
            depth += 1
        elif ch == ")":
            depth -= 1
            if depth == 0:
                return text[i:j + 1]
    raise ValueError("blocco non bilanciato: " + name)


def tokenize(s):
    out = []
    i = 0
    while i < len(s):
        c = s[i]
        if c in "()":
            out.append(c)
            i += 1
        elif c.isspace():
            i += 1
        elif c == DQ:
            j = i + 1
            buf = []
            while s[j] != DQ or s[j - 1] == "\\":
                buf.append(s[j])
                j += 1
            out.append(DQ + "".join(buf))
            i = j + 1
        else:
            j = i
            while j < len(s) and not s[j].isspace() and s[j] not in "()":
                j += 1
            out.append(s[i:j])
            i = j
    return out


def parse(s):
    toks = tokenize(s)
    pos = [0]

    def rd():
        t = toks[pos[0]]
        pos[0] += 1
        if t == "(":
            lst = []
            while toks[pos[0]] != ")":
                lst.append(rd())
            pos[0] += 1
            return lst
        return t

    return rd()


def sym_pins(block):
    """{numero: (x, y, angolo)} nel sistema di riferimento del simbolo."""
    tree = parse(block)
    pins = {}

    def walk(node):
        if not isinstance(node, list):
            return
        if node and node[0] == "pin":
            at = num = None
            for it in node[1:]:
                if isinstance(it, list) and it[0] == "at":
                    ang = float(it[3]) if len(it) > 3 else 0.0
                    at = (float(it[1]), float(it[2]), ang)
                if isinstance(it, list) and it[0] == "number":
                    num = it[1].lstrip(DQ)
            if at and num is not None:
                pins[num] = at
        for it in node:
            walk(it)

    walk(tree)
    return pins


CACHE = {}


def get_symbol(lib_id):
    if lib_id in CACHE:
        return CACHE[lib_id]
    lib, name = lib_id.split(":", 1)
    text = open(LIBS[lib], encoding="utf-8").read()
    block = find_block(text, name)
    CACHE[lib_id] = (block, sym_pins(block))
    return CACHE[lib_id]


def uid():
    return str(uuid.uuid4())


# ---------------------------------------------------------------- distinta base
FP_R = "Resistor_SMD:R_0402_1005Metric"
FP_C4 = "Capacitor_SMD:C_0402_1005Metric"
FP_C6 = "Capacitor_SMD:C_0603_1608Metric"
FP_C12 = "Capacitor_SMD:C_1206_3216Metric"
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

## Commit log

2026-08-19 Add BOM documentation and firmware calibration protocol
    - Created a new BOM document for JLCPCB with verified components and production parameters.
    - Added detailed notes on component selection and assembly requirements.
    - Introduced a firmware calibration protocol outlining two versions: logger and product.
    - Defined data collection sessions and validation rules for accurate step counting.
    - Established a structured approach for firmware development and implementation.
    - Included initial KiCad PCB and schematic files for the hardware design.
    [contapassi.kicad_pcb, contapassi.kicad_sch]
2026-08-19 Add design documentation, BOM, and firmware calibration protocol for high-precision step counter
    - Created design document (01-design.md) outlining objectives, hardware architecture, and key decisions.
    - Established BOM and checklist for JLCPCB (02-bom-jlcpcb.md) with verified components and tooling information.
    - Developed firmware and calibration protocol (03-firmware-taratura.md) detailing logger and product versions, data collection methods, and implementation order.
2026-08-19 Update PCB dimensions and component specifications in design documents
2026-08-19 Add new component models and scripts for schematic generation
    - Added SOT-23-5 and SOT-23 models for components C14879 and C15127.
    - Introduced WSON-8 model for component C97522.
    - Created a script to assign electrical types to pins in generated symbols, ensuring accurate ERC checks.
    - Developed a schematic generation script for the contapassi project, creating a netlist based on component connections.
    [contapassi.kicad_sch]
2026-08-19 Add scripts for generating PCB footprints and initial PCB layout
    - Implemented gen_footprints.py to create footprints for pogo pads and battery cell connections.
    - Implemented gen_pcb.py to generate the initial PCB layout, including component placement, keepout areas, and ground planes.
    - Both scripts utilize a structured approach to ensure compatibility with KiCad and maintain clear documentation within the code.
    [contapassi.kicad_pcb, contapassi.kicad_sch]
2026-08-19 Update battery specifications and charging details in BOM and design documents
2026-08-20 Add routing functionality for PCB generation
    - Introduced a new routing module (`route.py`) to handle the routing of pads on the PCB.
    - Implemented a grid-based routing algorithm using Lee's algorithm for pathfinding.
    - Enhanced `gen_pcb.py` to integrate routing capabilities, including segment generation for both front and back copper layers.
    - Added functions to manage pad placement and via creation adjacent to pads.
    - Updated the PCB generation process to include routing results in the final output.
    - Improved error handling and logging for unconnected pads during routing.
    [contapassi.kicad_pcb]
